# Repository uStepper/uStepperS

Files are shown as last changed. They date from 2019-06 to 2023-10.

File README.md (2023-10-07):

# uStepper S

The library contains support for driving the stepper, reading out encoder data. A few examples are included to show the functionality of the library.
The library is supported and tested with in Arduino IDE 1.8.11.

For more information, visit www.ustepper.com

## !! EEPROM Usage information !!

Please be aware that the uStepper uses the EEPROM to store settings related to the Dropin application.
If you are not using this, then this has no impact for your application, and you can ignore this section !

EEPROM address 0 to 15 contains the different settings for dropin. If your application uses the EEPROM,
Please use another location than these !

## Installation

Installation is split into two parts - Hardware and Library. Both are required to use the uStepper S boards.

### Hardware Installation 

### Instructions for users with the hardware for the original uStepper (the one before S and S lite) installed

To add hardware support for uStepper in the Arduino IDE (1.8.8+) do the following:
 - Open Arduino
 - Go to "Tools->Board->Boards Manager..."
 - Search for "uStepper"
 - Choose the "uStepper" board and press "Remove" button
 - close the Boards Manager
 - Go to "File->preferences"
 - Almost at the bottom there is a field stating: "Additional Boards Manager URLs" replace your currently inserted uStepper URL this URL: https://raw.githubusercontent.com/uStepper/uStepperHardware/master/package_ustepper_index.json
 - Press OK
 - Go to "Tools->Board->Boards Manager..."
 - Go to the bottom (after it has loaded new files) select "uStepper by ON Development IVS" and press install

### Instructions for users new to uStepper

To add hardware support for uStepper in the Arduino IDE (1.8.8+) do the following:
 - Open Arduino
 - Go to "File->preferences"
 - Almost at the bottom there is a field stating: "Additional Boards Manager URLs" insert this url: https://raw.githubusercontent.com/uStepper/uStepperHardware/master/package_ustepper_index.json
 - Press OK
 - Go to "Tools->Board->Boards Manager..."
 - Go to the bottom (after it has loaded new files) select "uStepper by ON Development IVS" and press install

You have now added uStepper hardware support and should be able to select uStepper under tools -> boards.

### Library Installation

To add the uStepper S library do the following:
- Open Arduino IDE (Version 1.8.8 or above)
- Go to "Sketch->Include Library->Manage Libraries..."
- Search for "uStepper S"
- Select "uStepper S" and press install
- Close Library Manager

## Documentation
The documentation for this library can be found at the following URL:

http://ustepper.com/docs/usteppers/html/index.html

### MAC (and a few Windows) Users:
In order to make the uStepper S show up in the "ports" list, you need to install the VCP driver from the following link: 
https://www.silabs.com/products/development-tools/software/usb-to-uart-bridge-vcp-drivers

## Known bugs
- does not properly release motor in dropin mode

## Change Log
2.3.2:
- added new python control example
- fixed encoder stall examples
- removed debug setup of pin on portB as output
  
2.3.1:
- added 6 new examples

2.3.0:
- Changed Servo library (uStepperServo.cpp) to use timer PWM instead of polling to control servo motors. 
- Changed the servo library example to use the new servo implementation.
- Changed the 'stop' method at the uStepperS.cpp to wait until the motor realy stops movement. Thanks to Daniel-Walther for pointing it out.

2.2.1:
- Added timeout to homing function

2.2.0:
- Added function to get current driver speed in RPM (getDriverRPM())
- Fixed "getVelocity()" method of "uStepperDriver" class to use correct twos complement conversion
- Updated keywords
- Added two new examples:
	- GYROBalance: Example on how to use MPU6050 IMU with uStepper S 
	- SWiFiGUI: Example sketch to control the uStepper S with browser based GUI over WiFi

2.1.0:
- Fixed checkOrientation to work with Closed loop and dropin modes
- Fixed stallguard feature
- Modified examples to library update  

2.0.0:
- Changed name of "brake()" function in uStepper Class to "setBrakeMode()"
- Implemented "setBrakeMode()" function in uStepper Class to choose between freewheel, braking with low side fets shorted and brake with specified hold current. default = brake with low side fets shorted
- "setHome" argument of ustepper class "setup" function is now used
- Implemented "checkOrientation()" function in uStepper Class, to check the orientation of the motor cable, and invert direction if needed.
- Added 3 moves in "checkOrientation()" function in uStepper Class, to check orientation instead of just 1
- Removed check for motor cable orientation from "setup()" function in uStepper Class. Users actively needs to call the "checkOrientation" function from uStepper Class, if they need this feature, AFTER calling the "setup()" function
- Disabled driver on MCU reset while setting up, to avoid the motor spinning on startup if power was removed during motor movement
- Moved the absolute position counter into the encoder getangle function
- Added a LP filter on the absolute position data in the encoder function (so, getAngleMoved is filtered)
- Stall detection removed from timer1
- Variable filter depending on mode set in setup routine
- Removed obsolete things in setup routine and timer1
- Made new velocity measurement for encoder values
- Made the control threshold for closed loop control variable and intrduced a function for editing it
- Changed timer1 interrupt frequency to 2KhZ for all other modes than DROPIN
- Added option to choose how long the "checkOrientation()" function in UstepperS class should move during check
- Renamed "PID" to "CLOSEDLOOP" to avoid confusing the closed loop position mode with a PID controller. PID keyword is stall accepted for backwards compatibility

1.0.1:
- Fixed bug in functions to set acceleration and deceleration
- moved a couple of functions in uStepperDriver.h from public to protected section of class
- added documentation

1.0.0:
- Bug fixes
- New Dropin PID code
- Added dropin CLI interface
- Fixed stall detection, and added user sensitivity parameter

0.1.1:
- Bug fixes

0.1.0:	
- Initial release

<br /><span xmlns:dct="http://purl.org/dc/terms/" property="dct:title">uStepper</span> by <a xmlns:cc="http://creativecommons.org/ns#" href="www.ustepper.com" property="cc:attributionName" rel="cc:attributionURL">ON Development</a> is licensed under a <a rel="license" href="http://creativecommons.org/licenses/by-nc-sa/4.0/">Creative Commons Attribution-NonCommercial-ShareAlike 4.0 International License</a>.

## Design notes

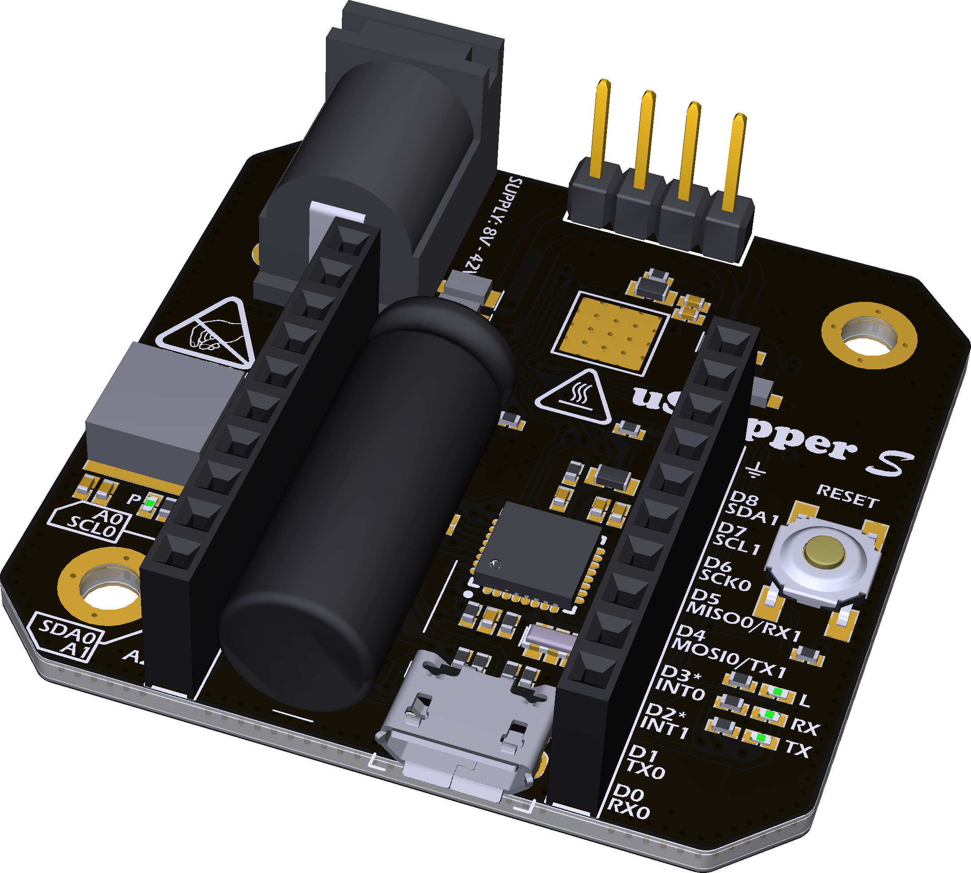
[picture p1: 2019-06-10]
Hardware/Board.png

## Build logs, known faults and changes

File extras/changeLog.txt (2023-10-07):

Changelog - uStepper S library
----------------------------
Version 2.3.2:
- added new python control example
- fixed encoder stall examples
- removed debug setup of pin on portB as output

Version 2.3.1:
	- added 6 new examples

Version 2.3.0:
	- Changed Servo library (uStepperServo.cpp) to use timer PWM instead of polling to control servo motors. 
	- Changed the servo library example to use the new servo implementation.
	- Changed the 'stop' method at the uStepperS.cpp to wait until the motor realy stops movement. Thanks to Daniel-Walther for pointing it out.

Version 2.2.1:
	- Added timeout to homing function

Version 2.2.0:
	- Added function to get current driver speed in RPM (getDriverRPM())
	- Fixed "getVelocity()" method of "uStepperDriver" class to use correct twos complement conversion
	- Updated keywords
	- Added two new examples:
		- GYROBalance: Example on how to use MPU6050 IMU with uStepper S 
		- SWiFiGUI: Example sketch to control the uStepper S with browser based GUI over WiFi

Version 2.1.0:
	- Fixed checkOrientation to work with Closed loop and dropin modes
	- Fixed stallguard feature
	- Modified examples to library update

Version 2.1.0:
	- Fixed checkOrientation to work with Closed loop and dropin modes
	- Fixed stallguard feature
	- Modified examples to library update  
	
Version 2.0.0:
	- Changed name of "brake()" function in uStepper Class to "setBrakeMode()"
	- Implemented "setBrakeMode()" function in uStepper Class to choose between freewheel, braking with low side fets shorted and brake with specified hold current. default = brake with low side fets shorted
	- "setHome" argument of ustepper class "setup" function is now used
	- Implemented "checkOrientation()" function in uStepper Class, to check the orientation of the motor cable, and invert direction if needed.
	- Added 3 moves in "checkOrientation()" function in uStepper Class, to check orientation instead of just 1
	- Removed check for motor cable orientation from "setup()" function in uStepper Class. Users actively needs to call the "checkOrientation" function from uStepper Class, if they need this feature, AFTER calling the "setup()" function
	- Disabled driver on MCU reset while setting up, to avoid the motor spinning on startup if power was removed during motor movement
	- Moved the absolute position counter into the encoder getangle function
	- Added a LP filter on the absolute position data in the encoder function (so, getAngleMoved is filtered)
	- Stall detection removed from timer1
	- Variable filter depending on mode set in setup routine
	- Removed obsolete things in setup routine and timer1
	- Made new velocity measurement for encoder values
	- Made the control threshold for closed loop control variable and intrduced a function for editing it
	- Changed timer1 interrupt frequency to 2KhZ for all other modes than DROPIN
	- Added option to choose how long the "checkOrientation()" function in UstepperS class should move during check
	- Renamed "PID" to "CLOSEDLOOP" to avoid confusing the closed loop position mode with a PID controller. PID keyword is stall accepted for backwards compatibility

Version 1.0.1:
	- Fixed bug in functions to set acceleration and deceleration
	- moved a couple of functions in uStepperDriver.h from public to protected section of class
	- added documentation
	
Version 1.0.0:
	- Bug fixes
	- New Dropin PID code
	- Added dropin CLI interface
	- Fixed stall detection, and added user sensitivity parameter

Version 0.1.1:
	- Bug fixes

Version 0.1.0:	
	- Initial release

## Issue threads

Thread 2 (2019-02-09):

Update readme

ghulands, 2019-02-09:
The readme says to follow the original documentation which talks about the ftdichip vcp. uStepper S uses the Silicon Labs VCP. It might save someone else 10 minutes why the port doesn't show up in the Arduino environment. ;-)

uStepper, 2019-02-10:
Thank you for noticing !
I will have the readme updated soon. are you using a mac?
Best Regards,
Thomas Olsen

ghulands, 2019-02-18:
Yes, using macOS.

sfandersen, 2019-02-19:
I am using Windows 10. It the uStepperS did not show up as a serial port before I downloaded this driver: https://www.silabs.com/products/development-tools/software/usb-to-uart-bridge-vcp-drivers

uStepper, 2019-02-27:
Thanks for pointing out that this issue can also occur on windows 10 !

Closed 2019-02-27.

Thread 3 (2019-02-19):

The max velocity seems wrong

sfandersen, 2019-02-19:
I think the max value that can be set is for VMAX should be 0x7FFE00

See the driver documentation:
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

I think the code should be:
	if( abs(velocity * this->microSteps) > (float)(0x7FFE00)) {
		velocity = (float)0x7FFE00 / this->microSteps;
	}

See:
https://github.com/uStepper/uStepperS/blob/2ae15273d868393d964261376dd657c965204c8a/src/uStepperS.cpp#L291

uStepper, 2019-02-27:
You are correct, this will be updated in next release !

sfandersen, 2019-04-29:
I would suggest only closing the bugs that are fixed.

Closed 2019-02-27.

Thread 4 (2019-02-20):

Overflow bug in stepper setup

matt-phair, 2019-02-20:
in `uStepperS::setup`, there is the line:

```
this->angleToStep = (float)(this->fullSteps*this->microSteps)/360.0;
```

by default, `microSteps` is `256` so if we call `setup` with `stepsPerRevolution` equal to anything over 256, the above will overflow.

This is a problem for (as an example) this motor: https://www.omc-stepperonline.com/nema-17-bipolar-09deg-46ncm-651ozin-2a-28v-42x42x48mm-4-wires-17hm19-2004s.html which has 400 steps per revolution.

The code could be corrected to be something like:

```
this->angleToStep = (float)this->fullSteps * (float)this->microSteps / 360.0
```

uStepper, 2019-04-09:
corrected for the upcoming version . Thanks for the input !

Closed 2019-04-09.

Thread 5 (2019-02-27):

No hard stop

matt-phair, 2019-02-27:
I'm working on implementing my own limit switches, andI might be missing something, but I can't reliably achieve a full hard stop.

`uStepper::stop()` still does a ramp down. At the moment, I'm trying to use something like this:

```
void stop() {
  stepper.driver.reset();
  delay(1000);
  stepper.setup(NORMAL, STEPS_PER_REVOLUTION);
  stepper.setMaxAcceleration(MAX_ACCELERATION);
  stepper.setMaxVelocity(MAX_VELOCITY);
  delay(1000);
}
```

But if this happens in the middle of a very long move, when `stepper.setup(...)` is called, it tries to finish the move it was originally in. If I can reset the current ramp profile, then maybe that will help the reset process?

Or if I'm way off base and there's a simple single line function to call to stop, then can someone point me in that direction?

uStepper, 2019-02-27:
Hi Matt,

A simple solution is to just set the max acceleration to a high value, call the stop function, and set the acceleration value back to normal after the motor has stopped:

`
void stop() {
  stepper.setMaxAcceleration(65535);
  stepper.stop();
  delay(100);
  stepper.setMaxAcceleration(MAX_ACCELERATION);
}
`
I hope this can help solving your issue

matt-phair, 2019-02-27:
@uStepper that solved it, thanks!

Closed 2019-02-27.

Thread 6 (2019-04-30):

Arduino error: Error compiling for board uStepper

derekcovill, 2019-04-30:
Hi there , I recently purchased a ustepper S, and I’ve installed the libraries for this in my Arduino (v 1.8.9...I'm not using the app) and have selected the uStepper board at the bottom of the list of boards, but when I try to run one of the example sketches (e.g. bounce) there is always the following error……….

In file included from
 ...\Arduino\libraries\uStepper_S\Examples\Bounce\Bounce.ino:1:0:

...\Arduino\libraries\uStepper_S\src/uStepperS.h:38:3: error: #error !!This library only supports the ATmega328PB MCU!!

  #error !!This library only supports the ATmega328PB MCU!!

   ^

exit status 1
Error compiling for board uStepper.

Just wondering if you have any advice for this? I’ve tried all the examples from uStepper, UstepperS and UstepperS lite also…

uStepper, 2019-04-30:
Hi Derek,

The problem is that you selected the "ustepper" board. You need to select the "ustepper S" board , if this is the type you have

Best regards
Thomas olsen

derekcovill, 2019-04-30:
Hi Thomas, but there doesn’t seem to be a ustepper S option? [image1.jpeg]

On 30 Apr 2019, at 17:26, uStepper <notifications@github.com<mailto:notifications@github.com>> wrote:

Hi Derek,

The problem is that you selected the "ustepper" board. You need to select the "ustepper S" board , if this is the type you have

Best regards
Thomas olsen

—
You are receiving this because you authored the thread.
Reply to this email directly, view it on GitHub<https://github.com/uStepper/uStepperS/issues/6#issuecomment-488020625>, or mute the thread<https://github.com/notifications/unsubscribe-auth/AKRZVYPERNVGE63YAOI343DPTBXMVANCNFSM4HJMD54A>.

___________________________________________________________
This email has been scanned by MessageLabs' Email Security System
on behalf of the University of Brighton. For more information see:
https://staff.brighton.ac.uk/is/computing/Pages/Email/spam.aspx

___________________________________________________________
This email has been scanned by MessageLabs' Email Security System
on behalf of the University of Brighton. For more information see:
https://staff.brighton.ac.uk/is/computing/Pages/Email/spam.aspx

derekcovill, 2019-04-30:
I did that but will try it again, perhaps I didn’t do it correctly, fingers crossed and many thanks for your help!

On 30 Apr 2019, at 17:55, uStepper <notifications@github.com<mailto:notifications@github.com>> wrote:

Then it is because you only installed the library, and not the hardware package. Please read the "hardware" part under "installation" on the readme page:
https://github.com/uStepper/uStepperS/blob/master/README.md

—
You are receiving this because you authored the thread.
Reply to this email directly, view it on GitHub<https://github.com/uStepper/uStepperS/issues/6#issuecomment-488030467>, or mute the thread<https://github.com/notifications/unsubscribe-auth/AKRZVYIVKJEQKI5FCA6GBI3PTB2W5ANCNFSM4HJMD54A>.

___________________________________________________________
This email has been scanned by MessageLabs' Email Security System
on behalf of the University of Brighton. For more information see:
https://staff.brighton.ac.uk/is/computing/Pages/Email/spam.aspx

___________________________________________________________
This email has been scanned by MessageLabs' Email Security System
on behalf of the University of Brighton. For more information see:
https://staff.brighton.ac.uk/is/computing/Pages/Email/spam.aspx

derekcovill, 2019-04-30:
Ok, I uninstalled the old one, updated it to the new one and that seemed to work, many thanks!

From: uStepper <notifications@github.com>
Reply-To: uStepper/uStepperS <reply@reply.github.com>
Date: Tuesday, 30 April 2019 at 17:55
To: uStepper/uStepperS <uStepperS@noreply.github.com>
Cc: Derek Covill <D.Covill@brighton.ac.uk>, Author <author@noreply.github.com>
Subject: Re: [uStepper/uStepperS] Arduino error: Error compiling for board uStepper (#6)

Then it is because you only installed the library, and not the hardware package. Please read the "hardware" part under "installation" on the readme page:
https://github.com/uStepper/uStepperS/blob/master/README.md

—
You are receiving this because you authored the thread.
Reply to this email directly, view it on GitHub<https://github.com/uStepper/uStepperS/issues/6#issuecomment-488030467>, or mute the thread<https://github.com/notifications/unsubscribe-auth/AKRZVYIVKJEQKI5FCA6GBI3PTB2W5ANCNFSM4HJMD54A>.

___________________________________________________________
This email has been scanned by MessageLabs' Email Security System
on behalf of the University of Brighton. For more information see:
https://staff.brighton.ac.uk/is/computing/Pages/Email/spam.aspx

___________________________________________________________
This email has been scanned by MessageLabs' Email Security System
on behalf of the University of Brighton. For more information see:
https://staff.brighton.ac.uk/is/computing/Pages/Email/spam.aspx

Closed 2019-05-15.

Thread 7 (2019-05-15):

Changing Hold Current bug

justinchan91, 2019-05-15:
When changing the max current to 80% using:

void setup(void)
{
 stepper.setup(PID);
  delay(1000);
  stepper.setMaxAcceleration(500);
  stepper.setMaxVelocity(800);
  **stepper.setCurrent(80.0);**
}

void loop(void){
  if(!stepper.getMotorState())
  {
    delay(500);
    stepper.moveToAngle(angle);
    angle = -angle;
  }

Any value around 70%-100% gives a random jerking. At start, while moving and sometimes at end where the motor stalls and then continues hap-hazardly.

max value according to datasheet is 31. The driver scales the input float and converts to a range of ints 0-31.

Using a stepper motor rated for up to 3A. Also tried w a smaller stepper motor-same issue.

uStepper, 2019-05-15:
Hi Justin,

Thank you for pointing this issue out. I will look into the cause and come up with a solution.

Best Regards,
Thomas Olsen

greyltc, 2020-02-02:
I see this too.

This isn't just for holding current though, it's for running current. My motors become increasingly unstable and unusable with current values beyond 50%. @uStepper, have you made any progress with solving this bug since last May?

Being limited to 50% of the design & advertised current or less seems like a pretty big deal.

uStepper, 2020-02-04:
Hi,

We have run a long term test on the NEMA 17 motors we sell and use and we can't get the behavior you describe.

And yes it is reasonable to being limited to 50% max current without adding cooling. There's a lot of heat dissipated from the TMC5130 and thus things will heat up unless you add active cooling. It is the same as for any other stepper driver like the popular StepStick style drivers.

What motors are you using? And what supply voltage?

sriram198198, 2020-02-15:
Hi team,

As you have mentioned that you have tested and was unable to reproduce the behavior. I would like to know what is the max current you have tested with ?

I am planning to buy few tens of pieces but for my application 50 Percent ( 1 Amp of current is not sufficient in some cases)

I am curious to know If I Could go a bit higher like 60-70 Percent Current so that I get 1.5 Amps to 1.68 Amps out of Ustepper S version.

Thank you,
Sriram.

uStepper, 2020-02-17:
Hi,

So we did an additional test on a motor with a rated current of 2.1A. The test was done using the run continous example. A 24 V lab supply capable of providing 3A was used and for the tests with FAN I used a 24V fan mounted in a fancover. Heatsinks were mounted on all tests.
It is not surprising that the driver gets hot since the on resistance of the TMC5130 can be as high as ~1ohm per half bridge meaning that at full current 4W is developed in heat - which is quite a bit.

Motor: 17HS24-2104S
Room temperature: 22 deg C

Test 1:
Current setting Run/Hold: 50/50 %
Surface chip temp after 30 min: 75.3degree

Test 2:
The same as Test 1 but with fan:
Surface chip temp after 30 min: 42.6deg C

Test 3:
~30min - stopped due to fear of burning the motor
Current setting Run/Hold: 100/100 %
Surface chip temp after ~30 min: 91.3deg C
Motor temperature: 57deg C

None of the test showed any issues with movement

We do not recommend running your driver at high tempepratures. We do recommend that some thought is given on how you use the driver, e.g. lower hold current, do not use brake if not necessary (to avoid heating during standstill) and limit running current to what is necessary. Furthermore, keep the supply voltage as low as you can since a higher supply will generate more heat on the board in general - both on switch mode regulator and driver. So, if it is not strictly needed to run at e.g. 36V then lower your supply voltage to what is actually required. A good starting point is 12V which is sufficient for most applications.

wffbos, 2020-02-26:
Hi,
I can't find in the documentation how to translate the current which is set in percent to actual current (amperes). I can find this:
http://ustepper.com/docs/usteppers/html/uStepperS_8cpp_source.html#l00392
`void uStepperS::setCurrent( double current )
 {
     if( current <= 100.0 && current >= 0.0){
         // The current needs to be in the range of 0-31
         this->driver.current = ceil(0.31 * current);
     }else{
         // If value is out of range, set default
         this->driver.current = 16;
     }

     driver.updateCurrent();
 }`
What unit is the value 0-31? Amperes? mili-amperes?
I guess the driver can't be that smart and know the max current for my motor?

uStepper, 2020-02-26:
Hi,

the documentation is here:
[http://ustepper.com/docs/usteppers/html/classuStepperS.html#ac74e343f7ad81aa5c54a68f2514807fe](url)

the input to the function is in percent (0-100), and the driver is a 2A driver, so 0% = 0A and 100% = 2A.
the 0-31 values you refer to are the input for the register in the driver

no, the driver does not know your motor rating, so you will need to adjust this accordingly

Best Regards,
Thomas Olsen

Closed 2020-07-11.

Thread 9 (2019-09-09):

Reading encoder data

GabrielGms, 2019-09-09:
Hello, i'm working on my research and this board is exactly what i need, but i have a specific need, read the data used in PID controller on another board. I don't need write data, only read to control a second code, running in another microcontroller, using the output error, this is possible? how?

uStepper, 2019-09-09:
Hi,
That would require alteration of the library. It can be done, but it require some coding from you.

Best regards, Mogens

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

uStepper, 2019-10-16:
Closing issue due to long inactivity

Closed 2019-10-16.

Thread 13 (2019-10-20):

Available/reserverd features?

esaheiskanen, 2019-10-20:
Hi!

Which 328pb featuers are reserved for ustepper s? I just noteced that serial1 (pins 5&6) interfere with stepperdriver. Is there a way top make serial1 to work?

uStepper, 2019-10-21:
Hi Esa,

The Serial1 feature is not reserved on either the uStepper S or S Lite, and does not interfere with the stepper driver. I am using the Serial1 in some of my sketches to get data from a wifi module (without any hardware/software modification)

On the uStepper S, SPI1 is used for the stepper driver, so this peripheral is not available to the user. The schematics are available under the hardware folder in this repository, if you want to take a closer look on which peripherals and pins are available on the pin headers

Best Regards,
Thomas Olsen

Closed 2020-02-04.

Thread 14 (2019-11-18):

uStepperS::setup()'s "setHome" parameter appears to do nothing

JRVeale, 2019-11-18:
Looking in uStepperS.cpp, I can see `encoder.setHome()` is called twice during `setup()` (on first glance it seems to be being used to determine which direction to set the driver's direction to), regardless of the value of the `bool` parameter `setHome`. It appears that the `setHome` is actually not used anywhere at all.

One may want to use the encoder to receive absolute angles, and therefore wish to prevent encoder's `setHome()` function from being called by setting the value of `setHome` in `setup()` accordingly.

If I've understood the library correctly from my brief look, I suggest changing `setup()` to call `encoder.getAngle()` twice to determine the direction to set for the driver (instead of calling `encoder.setHome()` at the start of `setup()` and then using `encoder.getAngleMoved()`). The final call to `encoder.setHome()` will then only occur if `setup()` has been called with the `setHome` parameter as `true`. This should preserve current behaviour while adding the option to leave the encoder as absolute.

(As an aside, thanks for open-sourcing and I have to say I appreciate how easy it is to skim through the uStepper code and understand the structure of what appears to be going on.)

JRVeale, 2019-11-18:
Actually, I'll try this quickly and if it seems to work without obvious issue I'll open a PR

uStepper, 2019-11-19:
Hi James,

Your suggestion is exactly how it is supposed to work. I don't know how we overlooked this, but the feature is not implemented for some reason. I will add this to the next release !

It is good to hear you are happy with the open-sourcing and the code structure, although i personally think it has gotten pretty messy in most places and could use a clean up ! ;)

Best Regards,
Thomas Olsen

JRVeale, 2019-11-19:
Far be it from me to judge anyone else's code smell!

uStepper, 2020-07-11:
Fixed :)

Best regards,
Mogens

Closed 2020-07-11.

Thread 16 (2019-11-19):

Question: Purpose of 10s delay during setup in DROPIN mode?

JRVeale, 2019-11-19:
Question in the title. Are there any adverse effects by removing (or shortening) this delay?

uStepper, 2019-11-30:
Hi,

The reason this delay was added initially was because during power up, when the printer controller board was connected to the uSteppers, some "garbage" signals sometimes occured on the step/dir/ena lines, making the system behave strange.

That said, this delay might not be needed in all setups, we just chose to keep it, as it was needed in our case

Best Regards,
Thomas Olsen

Closed 2020-02-04.

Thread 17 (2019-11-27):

SetHome - is my requirement possible

thehelpless, 2019-11-27:
Hi,

I am new to the ustepper and ustepper library.

I am building a camera slider on a linear belt driven rail using a nema 23 and a ustepperS

I want to create a homing routing that does the following (can be on each reset - no need to store long term)

On power on;

move the gantry CW and detect "home" position and set this as "0" steps
move the gantry CCW and detect "end" position and set this as "nSteps" from home.

I want this to be in steps rather than degrees (although I could divide degrees by step angle if needed)

Is the above possible with the ustepper library?

Thanks

uStepper, 2019-11-30:
Hi,
Yes, the above is possible by using the "moveToEnd()" function of the library. This function will move in your desired direction until it hits the endpoint, and return the distance from your starting point to the endpoint (in degrees):

`float railLength;`
`stepper.moveToEnd(CW,0.9);`
`stepper.encoder.setHome();`
`railLength = stepper.moveToEnd(CCW,0.9);`

the "0.9" parameter is used to set the stall detection sensitivity, and should be between 0 and 1, with lower numbers being more sensitive to stall detections.

I hope the above was helpful !

Best Regards,
Thomas Olsen

thehelpless, 2019-12-05:
Hi Thomas,

Thanks for your input / help and the time taken to read my mail! - the code example you provided worked perfectly,

`#include <uStepperS.h>

uStepperS stepper;
float railLength;
int railSteps;

void setup() {
  stepper.setup();
  Serial.begin(9600);

   while(!Serial.available());
  stepper.moveToEnd(CCW,0.9);
  stepper.encoder.setHome();
  railLength = stepper.moveToEnd(CW,0.9);
  Serial.println(railLength);
  railSteps = railLength/1.8;

}`

Thanks again

Closed 2019-12-05.

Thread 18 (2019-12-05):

moveAngle v moveToAngle

thehelpless, 2019-12-05:
Hi,

In the class list for the uStepper S there is both moveAngle and moveToAngle.
The descriptions for the two are identical, however the code is not.

Am i right that moveAngle is relative while moveToAngle is absolute based on the initiation of PID and using setHome?

Thanks

uStepper, 2019-12-08:
Hi,

That is not intended that the documentation is identical.

But yes, you are absolutely correct

Best Regards,
Thomas Olsen

uStepper, 2020-07-11:
Corrected the description in the develop branch

Best regards,
Mogens

Closed 2020-07-11.

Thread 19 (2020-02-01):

StallGuard2 support?

greyltc, 2020-02-01:
It seems like your stall detection implementation here could be improved. Why not make use of the StallGuard2 feature in the TMC5130A? That should be much more robust and performant than what you have now.

uStepper, 2020-02-04:
Hi,

We did it the way we did to make the implementation the same for both the S and the S-lite. But we are looking in to stallguard already as we could use the processing power for other tasks than stall detection.

greyltc, 2020-02-04:
Also, the driver IC can keep track of the encoder counts so you don't have to do that on the microcontroller.

uStepper, 2020-02-05:
Hi,

I agree with you, that could be helpful, however there are a few issues, why this may not be an ideal solution

first of all we would loose 2 bits of resolution by using the ABI interface of the encoder.

secondly, one of our current issues is noise on the encoder readings, which we are currently working on solving by adding a filter to the encoder output. this noise will be present on the ABI output aswell, and since it goes directly into the driver chip, we won't be able to mitigate the problem at all

Closed 2021-01-22.

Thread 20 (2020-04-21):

Help walk me through setting up Ustepper S with 3D printer

dshield55, 2020-04-21:
Hoping for a walkthrough for using uStepper S boards on the X and Y of a 3D printer.

I'm a beginner. From info on the website, I think right now I have a PID problem. But I don't know how to determine or why to change either of those 3 variables.

I first tried the stock dropin example sketch that had P-75, I-7, D-1 (why is it higher than suggested PIDs elsewhere?)

I changed it to P-0.5, I-0.5, D-0 like the uStepper S product sheet said to try. That doesn't work either.

I don't know where to go from here because I have no idea how to determine what to change them to or why I'm changing them.

I think I set the hardware up correctly according to instructions and I have the latest board and library installed in Arduino IDE 1.8.1.2. I have an SKR V1.4 Turbo printer board with Marlin 2.0.5.2 firmware that was setup and working well. I commented out the drivers for the X and Y axis so it uses default settings for drivers and I can just run enable, step, dir, and ground pins from the driver sockets in the board up to the uStepperS.

I've attempted to print a calibration square. Shifts happen every time the direction is changed.  Normal behavior for my printer without uStepper is maybe once in 100 layers a single noticeable shift happens. This behaviour would be like a continuous shift that never stops shifting and each new layer starts farther up and to the right of the layer before it.

If I take motor off of printer and just run the motor with uStepperS, any time I change direction, it'll end up as much as 90 degrees off. Once I've gone one direction long enough it will consistently always advance the way it should, but if I switch directions again, it's going to get thrown off. There's lots of sudden accelerations, screeching, and knocking in the motor.

dshield55, 2020-04-28:
Problem was with magnets slipping during operation, not with PID.

Closed 2020-04-28.

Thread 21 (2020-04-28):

Permission denied in objcopy crtatmega328pb.o

HermanEldering, 2020-04-28:
I am using the Windows Store version of Arduino. When using the uStepperS board I get a permission denied error when it attempts to copy the crtatmega328pb file.

From this forum post it also appears to happen when the Arduino IDE is installed inside the program files folder: https://forum.arduino.cc/index.php?topic=638028.0

For now I've seemed to fix it by commenting out the lines below in the file "packages\uStepper\hardware\avr\2.2.0\platform.txt". I'm not sure if this will cause problems somewhere else but with these changes the bounce example compiles and runs on the board.

```
# Copy the startup and c runtime libs to the right folder / thx to elector
#recipe.hooks.linking.prelink.1.pattern="{compiler.path}{compiler.objcopy.cmd}" "{runtime.platform.path}/tools/lib/crtatmega328pb.o" "{runtime.tools.avr-gcc.path}/avr/lib/avr5/crtatmega328pb.o"
#recipe.hooks.linking.prelink.2.pattern="{compiler.path}{compiler.objcopy.cmd}" "{runtime.platform.path}/tools/lib/crtatmega328pb.o" "{runtime.tools.avr-gcc.path}/avr/lib/avr5/crtm328pb.o"
#recipe.hooks.linking.prelink.3.pattern="{compiler.path}{compiler.objcopy.cmd}" "{runtime.platform.path}/tools/lib/libatmega328pb.a" "{runtime.tools.avr-gcc.path}/avr/lib/avr5/libatmega328pb.a"
```

uStepper, 2020-04-30:
Hi Herman,

That issue is related to the windows store version of Arduino IDE, which currently have issue with some functions and boards. we recommend that you use the version downloaded directly from arduino.cc.

Best Regards,
Thomas Olsen

Closed 2020-04-30.

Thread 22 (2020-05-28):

Difference between MovedAngle and motor steps

Nestilaos, 2020-05-28:
Hi,

I observed with release 2.0.0 a difference between the moved angle and the steps ran by the motor. I am quite sure that the motor did not loose steps.

When running 51200 steps into one direction and then going back the initial angle is missed by approx. 20-40 deg according to getAngleMoved().

Is this anything known?

Regards.

Nestilaos, 2020-05-29:
I found the issue. The distance between encoder and magnet was too high. The status bit for "weak magnet field" was set.

Neither the "old" mounting bracket from uStepper/uStepper S-lite nor the newer one that allows permanent mounting can be used without modifications. The distance between magnet and encoder is just too high.

I could put some stripes of Tesa below the magnet. Now everything is working correctly as far as I can tell.

uStepper, 2020-07-11:
Hi,

Yeah we have noticed that the magnet strength is on the weak side. We cant recall this with our stock motors here though...

sliangder, 2021-05-09:
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

Closed 2020-07-11.

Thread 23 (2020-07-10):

ShaftOrientiation is not correctly maintained

Nestilaos, 2020-07-10:
Shaft orientation is set in the GCONF register of the driver and correctly set in the corresponding function inside uStepperDriver.cpp.

Unfortunately, the bit is not respected and set to zero, as soon as
- uStepperDriver::enableStealth()
- uStepperDriver::enableStallguard( int8_t threshold, bool stopOnStall )
- uStepperDriver::disableStallguard( void )
are called.

Therefore, in most of my scenarios the result of uStepperS::checkOrientation was not respected.

Best regards.

uStepper, 2020-07-11:
Hi - good catch :) We were already working on it and I have just pushed the corrected to the develop branch. When tested by a second party in our group we will merge into master and make a release with the fix.

Closed 2020-07-11.

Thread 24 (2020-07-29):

[FR] Support for Marlin 2.0.X Closed-loop controller function?

felixekman, 2020-07-29:
Are there any plans to expand support for Drop-in/replacement to be compatible with the new Marlin Firmware closed-loop controller functions? At a glance, it does not seem to be too difficult as it only requires the addition of two pins/variables:

#EXTERNAL_CLOSED_LOOP_CONTROLLER

CLOSED_LOOP_ENABLE_PIN        -1
CLOSED_LOOP_MOVE_COMPLETE_PIN -1

uStepper, 2023-08-13:
Support for the Marlin closed-loop firmware will not be implemented but it should be possible to do this by adding some functionality to our closedloop sketch for those two required I/O's

Closed 2023-08-13.

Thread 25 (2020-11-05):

example on how to use the other pins?

RobertoPuglieseFusco, 2020-11-05:
where can I find an example on how to use the other available pins?
for instance use PWM enabled pin to dim a light.
Thanks!

uStepper, 2021-01-22:
Hi Roberto,

This is done the same way as any other Arduino Board.
For general input/output pin usage check this guide:
https://www.allaboutcircuits.com/projects/learn-how-to-use-the-arduinos-digital-i-o/

for PWM, check out the following:
https://create.arduino.cc/projecthub/muhammad-aqib/arduino-pwm-tutorial-ae9d71

Best Regards,
Thomas Olsen

Closed 2021-01-22.

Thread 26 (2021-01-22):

Error compiling Continous.ino  / EEPROM / crtatmega328pb.o

LibrEars, 2021-01-22:
Hi uStepper-Team,

my trial to get the uStepperS working failed. I am running Debian 10 GNU/Linux and installed a new Arduino IDE via flatpack /flathub (v1.8.13) and followed the [steps](https://github.com/uStepper/uStepperS#instructions-for-users-new-to-ustepper) to install the uStepperS hard- and software.

Then I downloaded the Continous.ino example which does not compile (see error output below) - I even flashed the bootloader to be sure.

Do you now what might cause the error?  Also I am confused with the description of the EEPROM usage - an example-code or link for further information would help.

Thank you very much
LibrEars

```
Arduino: 1.8.13 (Linux), Board: "uStepperS"

/app/Arduino/arduino-builder -dump-prefs -logger=machine -hardware /app/Arduino/hardware -hardware /home/user/.arduino15/packages -tools /app/Arduino/tools-builder -tools /app/Arduino/hardware/tools/avr -tools /home/user/.arduino15/packages -built-in-libraries /app/Arduino/libraries -libraries /home/user/Arduino/libraries -fqbn=uStepper:avr:uStepperS -vid-pid=10C4_EA60 -ide-version=10813 -build-path /tmp/arduino_build_119629 -warnings=all -build-cache /tmp/arduino_cache_755599 -prefs=build.warn_data_percentage=75 -prefs=runtime.tools.avr-gcc.path=/app/Arduino/hardware/tools/avr -prefs=runtime.tools.avr-gcc-7.3.0-atmel3.6.1-arduino7.path=/app/Arduino/hardware/tools/avr -prefs=runtime.tools.avrdude.path=/app/Arduino/hardware/tools/avr -prefs=runtime.tools.avrdude-6.3.0-arduino17.path=/app/Arduino/hardware/tools/avr -prefs=runtime.tools.arduinoOTA.path=/app/Arduino/hardware/tools/avr -prefs=runtime.tools.arduinoOTA-1.3.0.path=/app/Arduino/hardware/tools/avr -verbose /home/user/Examples/Continous.ino/Continous/Continous.ino
/app/Arduino/arduino-builder -compile -logger=machine -hardware /app/Arduino/hardware -hardware /home/user/.arduino15/packages -tools /app/Arduino/tools-builder -tools /app/Arduino/hardware/tools/avr -tools /home/user/.arduino15/packages -built-in-libraries /app/Arduino/libraries -libraries /home/user/Arduino/libraries -fqbn=uStepper:avr:uStepperS -vid-pid=10C4_EA60 -ide-version=10813 -build-path /tmp/arduino_build_119629 -warnings=all -build-cache /tmp/arduino_cache_755599 -prefs=build.warn_data_percentage=75 -prefs=runtime.tools.avr-gcc.path=/app/Arduino/hardware/tools/avr -prefs=runtime.tools.avr-gcc-7.3.0-atmel3.6.1-arduino7.path=/app/Arduino/hardware/tools/avr -prefs=runtime.tools.avrdude.path=/app/Arduino/hardware/tools/avr -prefs=runtime.tools.avrdude-6.3.0-arduino17.path=/app/Arduino/hardware/tools/avr -prefs=runtime.tools.arduinoOTA.path=/app/Arduino/hardware/tools/avr -prefs=runtime.tools.arduinoOTA-1.3.0.path=/app/Arduino/hardware/tools/avr -verbose /home/user/Examples/Continous.ino/Continous/Continous.ino
Using board 'uStepperS' from platform in folder: /home/user/.arduino15/packages/uStepper/hardware/avr/2.2.1
Using core 'arduino' from platform in folder: /app/Arduino/hardware/arduino/avr
Detecting libraries used...
/app/Arduino/hardware/tools/avr/bin/avr-g++ -c -g -Os -w -std=gnu++11 -fpermissive -fno-exceptions -ffunction-sections -fdata-sections -fno-threadsafe-statics -flto -w -x c++ -E -CC -mmcu=atmega328pb -DF_CPU=16000000L -DARDUINO=10813 -DARDUINO_AVR_USTEPPER_S -DARDUINO_ARCH_AVR -I/home/user/.arduino15/packages/uStepper/hardware/avr/2.2.1/tools/include -D__AVR_DEV_LIB_NAME__=m328pb -I/app/Arduino/hardware/arduino/avr/cores/arduino -I/home/user/.arduino15/packages/uStepper/hardware/avr/2.2.1/variants/ustepperS /tmp/arduino_build_119629/sketch/Continous.ino.cpp -o /dev/null -DARDUINO_LIB_DISCOVERY_PHASE
Alternatives for uStepperS.h: [uStepper_S@2.2.0]
ResolveLibrary(uStepperS.h)
  -> candidates: [uStepper_S@2.2.0]
/app/Arduino/hardware/tools/avr/bin/avr-g++ -c -g -Os -w -std=gnu++11 -fpermissive -fno-exceptions -ffunction-sections -fdata-sections -fno-threadsafe-statics -flto -w -x c++ -E -CC -mmcu=atmega328pb -DF_CPU=16000000L -DARDUINO=10813 -DARDUINO_AVR_USTEPPER_S -DARDUINO_ARCH_AVR -I/home/user/.arduino15/packages/uStepper/hardware/avr/2.2.1/tools/include -D__AVR_DEV_LIB_NAME__=m328pb -I/app/Arduino/hardware/arduino/avr/cores/arduino -I/home/user/.arduino15/packages/uStepper/hardware/avr/2.2.1/variants/ustepperS -I/home/user/Arduino/libraries/uStepper_S/src /tmp/arduino_build_119629/sketch/Continous.ino.cpp -o /dev/null -DARDUINO_LIB_DISCOVERY_PHASE
Alternatives for EEPROM.h: [EEPROM@2.0 EEPROM@2.0]
ResolveLibrary(EEPROM.h)
  -> candidates: [EEPROM@2.0 EEPROM@2.0]
/app/Arduino/hardware/tools/avr/bin/avr-g++ -c -g -Os -w -std=gnu++11 -fpermissive -fno-exceptions -ffunction-sections -fdata-sections -fno-threadsafe-statics -flto -w -x c++ -E -CC -mmcu=atmega328pb -DF_CPU=16000000L -DARDUINO=10813 -DARDUINO_AVR_USTEPPER_S -DARDUINO_ARCH_AVR -I/home/user/.arduino15/packages/uStepper/hardware/avr/2.2.1/tools/include -D__AVR_DEV_LIB_NAME__=m328pb -I/app/Arduino/hardware/arduino/avr/cores/arduino -I/home/user/.arduino15/packages/uStepper/hardware/avr/2.2.1/variants/ustepperS -I/home/user/Arduino/libraries/uStepper_S/src -I/home/user/.arduino15/packages/uStepper/hardware/avr/2.2.1/libraries/EEPROM/src /tmp/arduino_build_119629/sketch/Continous.ino.cpp -o /dev/null -DARDUINO_LIB_DISCOVERY_PHASE
Using cached library dependencies for file: /home/user/Arduino/libraries/uStepper_S/src/uStepperDriver.cpp
Using cached library dependencies for file: /home/user/Arduino/libraries/uStepper_S/src/uStepperEncoder.cpp
Using cached library dependencies for file: /home/user/Arduino/libraries/uStepper_S/src/uStepperS.cpp
Using cached library dependencies for file: /home/user/Arduino/libraries/uStepper_S/src/uStepperServo.cpp
Generating function prototypes...
/app/Arduino/hardware/tools/avr/bin/avr-g++ -c -g -Os -w -std=gnu++11 -fpermissive -fno-exceptions -ffunction-sections -fdata-sections -fno-threadsafe-statics -flto -w -x c++ -E -CC -mmcu=atmega328pb -DF_CPU=16000000L -DARDUINO=10813 -DARDUINO_AVR_USTEPPER_S -DARDUINO_ARCH_AVR -I/home/user/.arduino15/packages/uStepper/hardware/avr/2.2.1/tools/include -D__AVR_DEV_LIB_NAME__=m328pb -I/app/Arduino/hardware/arduino/avr/cores/arduino -I/home/user/.arduino15/packages/uStepper/hardware/avr/2.2.1/variants/ustepperS -I/home/user/Arduino/libraries/uStepper_S/src -I/home/user/.arduino15/packages/uStepper/hardware/avr/2.2.1/libraries/EEPROM/src /tmp/arduino_build_119629/sketch/Continous.ino.cpp -o /tmp/arduino_build_119629/preproc/ctags_target_for_gcc_minus_e.cpp -DARDUINO_LIB_DISCOVERY_PHASE
/app/Arduino/tools-builder/ctags/5.8-arduino11/ctags -u --language-force=c++ -f - --c++-kinds=svpf --fields=KSTtzns --line-directives /tmp/arduino_build_119629/preproc/ctags_target_for_gcc_minus_e.cpp
Compiling sketch...
/app/Arduino/hardware/tools/avr/bin/avr-g++ -c -g -Os -Wall -Wextra -std=gnu++11 -fpermissive -fno-exceptions -ffunction-sections -fdata-sections -fno-threadsafe-statics -MMD -flto -mmcu=atmega328pb -DF_CPU=16000000L -DARDUINO=10813 -DARDUINO_AVR_USTEPPER_S -DARDUINO_ARCH_AVR -I/home/user/.arduino15/packages/uStepper/hardware/avr/2.2.1/tools/include -D__AVR_DEV_LIB_NAME__=m328pb -I/app/Arduino/hardware/arduino/avr/cores/arduino -I/home/user/.arduino15/packages/uStepper/hardware/avr/2.2.1/variants/ustepperS -I/home/user/Arduino/libraries/uStepper_S/src -I/home/user/.arduino15/packages/uStepper/hardware/avr/2.2.1/libraries/EEPROM/src /tmp/arduino_build_119629/sketch/Continous.ino.cpp -o /tmp/arduino_build_119629/sketch/Continous.ino.cpp.o
cc1plus: warning: type qualifiers ignored on function return type [-Wignored-qualifiers]
cc1plus: warning: type qualifiers ignored on function return type [-Wignored-qualifiers]
In file included from /home/user/Arduino/libraries/uStepper_S/src/uStepperS.h:152:0,
                 from /home/user/Examples/Continous.ino/Continous/Continous.ino:9:
/home/user/.arduino15/packages/uStepper/hardware/avr/2.2.1/libraries/EEPROM/src/EEPROM.h:145:20: warning: 'EEPROM' defined but not used [-Wunused-variable]
 static EEPROMClass EEPROM;
                    ^~~~~~
Compiling libraries...
Compiling library "uStepper_S"
Using previously compiled file: /tmp/arduino_build_119629/libraries/uStepper_S/uStepperDriver.cpp.o
Using previously compiled file: /tmp/arduino_build_119629/libraries/uStepper_S/uStepperEncoder.cpp.o
Using previously compiled file: /tmp/arduino_build_119629/libraries/uStepper_S/uStepperS.cpp.o
Using previously compiled file: /tmp/arduino_build_119629/libraries/uStepper_S/uStepperServo.cpp.o
Compiling library "EEPROM"
Compiling core...
Using precompiled core: /tmp/arduino_cache_755599/core/core_uStepper_avr_uStepperS_c05e25cd8a3f9a150fee831f71269750.a
Linking everything together...
/app/Arduino/hardware/tools/avr/bin/avr-objcopy /home/user/.arduino15/packages/uStepper/hardware/avr/2.2.1/tools/lib/crtatmega328pb.o /app/Arduino/hardware/tools/avr/avr/lib/avr5/crtatmega328pb.o
/app/Arduino/hardware/tools/avr/bin/avr-objcopy:/app/Arduino/hardware/tools/avr/avr/lib/avr5/crtatmega328pb.o: Das Dateisystem ist nur lesbar
Multiple libraries were found for "EEPROM.h"
 Used: /home/user/.arduino15/packages/uStepper/hardware/avr/2.2.1/libraries/EEPROM
 Not used: /app/Arduino/hardware/arduino/avr/libraries/EEPROM
Using library uStepper_S at version 2.2.0 in folder: /home/user/Arduino/libraries/uStepper_S
Using library EEPROM at version 2.0 in folder: /home/user/.arduino15/packages/uStepper/hardware/avr/2.2.1/libraries/EEPROM
exit status 1
Error compiling for board uStepperS.

```

uStepper, 2021-01-22:
Hi LibrEars,

The problem is not with the bootloader or the uStepper hardware/software.
The problem is that the following file is not readable on your arduino IDE installation:
   /app/Arduino/hardware/tools/avr/avr/lib/avr5/crtatmega328pb.o

I would suggest you to install the portable arduino IDE, downloaded directly from the arduino.cc website instead of the package manager you used.

Best Regards,
Thomas Olsen

LibrEars, 2021-05-18:
This solved the problem - Thank you!

Hint: You can use a virtual machine if you do want to sandbox the IDE

Closed 2021-05-18.

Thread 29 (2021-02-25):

[feature requests] hardware reset and interrupt lines

greyltc, 2021-02-25:
I wonder if in the next hardware revision you make you could tie pin 10 on the TMC driver (VCC_IO) to a pin on the microcontroller (or at least allow it to pull that line down momentarily).

This would allow the microcontroller to properly reset the driver IC. I'm not sure if there's an easy way in the current design to get all the driver's registers into a known state (is there?).

Also, would be great to have SWN_DIAG0 (pin 26) and SWP_DIAG1 (pin 27) from the stepper driver on interrupt enabled pins of the microcontroller!

uStepper, 2023-10-07:
Hi,

uStepper S will not receive further updates to hardware, and only limited updates to software.

however, we will take it into our considerations for our newest product, uStepper S32.

Best Regards
uStepper Team

Closed 2023-10-07.

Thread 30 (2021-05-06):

VCP driver for Windows 10

ghulands, 2021-05-06:
Hi,
I'm trying to help my friend set up the uStepper S environment on Windows 10, but when I plug in the usb on it, Windows 10 is not creating a virtual com port.

Which Virtual COM port driver do i need to install for the devices to appear in the Aurdino IDE?

Thanks,
Greg

uStepper, 2021-05-11:
Hi Greg,

You should install the following VCP driver:
https://www.silabs.com/documents/public/software/CP210x_Windows_Drivers.zip

Best regards,
Thomas Olsen

Closed 2023-08-13.

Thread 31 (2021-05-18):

Can't get interrupts to work

LibrEars, 2021-05-18:
Hi all,

i am trying to attach a [mechanical kill-switch](https://de.rs-online.com/web/p/mikroschalter/6821529/) (pulldown) to my setup in order to stop the motor in case my 'platform crashes into an object'.

The code works with an arduino but sadly not with the uStepperS. The digital pin itself works so I guess there is a problem with the interrupts..

Can somebody help :)?

Here is the code:

```
// Code used to test a kill-switch (pulldown configuration - with an external 10k resistor and the +5V source) with uStepperS

//include libraries
#include <math.h>

//Stop-switches definitions
#define stopSwPin 3 // pin with interrupt

//global variables
volatile int stopMove=0;        //stop-switch output
void stop_isr();
void waitForSerial();

//runs once
void setup() {
  Serial.begin(115200); //115200 is baud rate of serial comm

  //setup stop switches
  pinMode(stopSwPin, INPUT);
  attachInterrupt(digitalPinToInterrupt(stopSwPin),stop_isr,RISING);
  stopMove=0;
}

//runs forever
void loop() {

  int i,input_char;

  Serial.println("\nStart test switches? [y/n]");
  waitForSerial();

  for(i=0; i<5; i++){

    //check if stop switch was pressed
    if(stopMove==HIGH){
      Serial.println("MOTOR STOPPED");
      break;
    }

    }

    Serial.println("\nContinue to next test? [y/n]");
    waitForSerial();

}

//functions

void waitForSerial(){
  char input_char;

  while(Serial.available()==0);
  do{
    input_char= (char)Serial.read();
  }
  while(input_char!='y');
}

//stop switch interrupt handler
void stop_isr(){ //keep this function small!

  stopMove=HIGH;

}
```

LibrEars, 2021-05-21:
hi again,

i checked with another code for a simple button and LED toggle ([from here](https://www.electronicshub.org/arduino-interrupts-tutorial/)).  Still it works on the arduino (here I used pin 13 for the LED) but not for the uStepperS :/

```
int ledPin = A2;
int buttonPin = 3; // use simple button (rotary)

int ledToggle;
int previousState = HIGH;
unsigned int previousPress;
volatile int buttonFlag;
int buttonDebounce = 20;

void setup()
{
  //interrupts();
  pinMode(ledPin, OUTPUT);
  pinMode(buttonPin, INPUT_PULLUP);
  attachInterrupt(digitalPinToInterrupt(3), button_ISR, CHANGE);
}

void loop()
{
  if((millis() - previousPress) > buttonDebounce && buttonFlag)
  {
    previousPress = millis();
    if(digitalRead(buttonPin) == LOW && previousState == HIGH)
    {
      ledToggle =! ledToggle;
      digitalWrite(ledPin, ledToggle);
      previousState = LOW;
    }

    else if(digitalRead(buttonPin) == HIGH && previousState == LOW)
    {
      previousState = HIGH;
    }
    buttonFlag = 0;
  }
}

void button_ISR()
{
  buttonFlag = 1;
}
```

LibrEars, 2021-06-11:
Hi Again,

i got some progress by using [Pin Change Interrupts](https://www.teachmemicro.com/arduino-interrupt-tutorial/). They are different than normal Interrupts ("might be a tiny bit slower and not that reliable because of that detection overhead (talking about micro seconds)") but there is an [arduino library](https://www.arduino.cc/reference/en/libraries/pinchangeinterrupt/).

Still it is very confusing and frustrating that normal interrupts do not work. Could it be, that they are already in use by the [dropin feature](https://ustepper.com/docs/usteppers/html/classuStepperS.html#a7d9af270acb55589631319b0f5460276)? In my understanding they should not as long as you do not use this feature actively in your code... ?

Here is an example code for Pin Change Interrupts:

```
#include "PinChangeInterrupt.h"

// Choose a valid PinChangeInterrupt pin of your Arduino board
#define buttonPin 3
int LEDPin = A2;

void setup()
{

  // set pin to input with a pullup, led to output
  pinMode(buttonPin, INPUT_PULLUP);
  pinMode(LEDPin, OUTPUT);

  // Manually blink once to test if LED is functional
  blinkLed();
  delay(1000);
  blinkLed();

  // Attach the new PinChangeInterrupt and enable event function below

}

void loop()
{
 // Nothing to do here
}

// ISR
void blinkLed(void) {
  // Switch Led state
  digitalWrite(LEDPin, !digitalRead(LEDPin));
}
```

uStepper, 2023-10-07:
Hi,

The problem is in the "digitalPinToInterrupt(3)" function, having an implementation error.

this is fixed in the development branch of the hardware package, which will be released soon

Best Regards,
uStepper Team

Closed 2023-10-07.

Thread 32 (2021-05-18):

i2C example - Grove-LCD display (RGB Backlight)?

LibrEars, 2021-05-18:
Hi all,

did someone get the I2C ports SDA1 and SCL1 (Digital pins D7 & D8) of the uStepperS up running? I tried to connect a grove-LCD display (RGB Backlight) but it did not work so far.

The examples of the [grove library](https://github.com/Seeed-Studio/Grove_LCD_RGB_Backlight) did not work and I also tried without success to detect the I2C ports in general with the i2c_scanner from the arduino uno examples (with and without the pins connected, code see below)

The scanner uses the wire library. Does someone knows if this should work in principle or is there more hard stuff necessary to get it running?

```
// --------------------------------------
// i2c_scanner
//
// Version 1
//    This program (or code that looks like it)
//    can be found in many places.
//    For example on the Arduino.cc forum.
//    The original author is not know.
// Version 2, Juni 2012, Using Arduino 1.0.1
//     Adapted to be as simple as possible by Arduino.cc user Krodal
// Version 3, Feb 26  2013
//    V3 by louarnold
// Version 4, March 3, 2013, Using Arduino 1.0.3
//    by Arduino.cc user Krodal.
//    Changes by louarnold removed.
//    Scanning addresses changed from 0...127 to 1...119,
//    according to the i2c scanner by Nick Gammon
//    https://www.gammon.com.au/forum/?id=10896
// Version 5, March 28, 2013
//    As version 4, but address scans now to 127.
//    A sensor seems to use address 120.
// Version 6, November 27, 2015.
//    Added waiting for the Leonardo serial communication.
//
//
// This sketch tests the standard 7-bit addresses
// Devices with higher bit address might not be seen properly.
//

#include <Wire.h>

void setup() {
  Wire.begin();

  Serial.begin(9600);
  while (!Serial); // Leonardo: wait for serial monitor
  Serial.println("\nI2C Scanner");
}

void loop() {
  int nDevices = 0;

  Serial.println("Scanning...");

  for (byte address = 1; address < 127; ++address) {
    // The i2c_scanner uses the return value of
    // the Write.endTransmisstion to see if
    // a device did acknowledge to the address.
    Wire.beginTransmission(address);
    byte error = Wire.endTransmission();

    if (error == 0) {
      Serial.print("I2C device found at address 0x");
      if (address < 16) {
        Serial.print("0");
      }
      Serial.print(address, HEX);
      Serial.println("  !");

      ++nDevices;
    } else if (error == 4) {
      Serial.print("Unknown error at address 0x");
      if (address < 16) {
        Serial.print("0");
      }
      Serial.println(address, HEX);
    }
  }
  if (nDevices == 0) {
    Serial.println("No I2C devices found\n");
  } else {
    Serial.println("done\n");
  }
  delay(5000); // Wait 5 seconds for next scan
}
```

LibrEars, 2021-06-25:
I made some progress. Turns out I should have used SDA0 and SDA1 from the start and then it works.

Also I found out, that the analog pins A0 and A2 are not labeled right on the board! (they need to be swaped)! I will open a new issue for that.

Also pin D7 (SCL1) and D8 (SDA1) are somehow always HIGH (missing pullup resistor?) which causes problems in my setup (not enough pins). If you for some reason need to use the SCL1 and SDA1 pins for the display (or similar) as well, I found a way :)

This is not possible by default due to missing firmware. Therefore we need to add support for the microcontroller. Here is what I did:

1. Go to the folder \Arduino\libraries and copy the folder \Grove_-_LCD_RGB_Backlight and rename it to \Grove_-_LCD_RGB_Backlight_Serial1
2. In the Folder \Grove_-_LCD_RGB_Backlight_Serial1 rename the files rgb_lcd.cpp and rgb_lcd.h to rgb_lcd1.cpp and rgb_lcd1.h
3. Open the file rgb_lcd1.cpp with an text editor and change the lines  #include <Wire.h> to #include <Wire1.h> #include "rgb_lcd.h" to #include "rgb_lcd1.h"
Also add the line
extern TwoWire1 Wire1; // insert this line is the modification to include Wire1 (SDA1 / SCL1) .…
    5. Then press ‘Ctrl+h’  to replace all function calls starting with Wire.xxx() with Wire1.xxx()
! Make sure to not replace the lines added above a second time
    6. From now on in the arduino code always include #include <Wire1.h> and #include "rgb_lcd1.h"

Sources:
    • https://github.com/MCUdude/MiniCore This lib adds support for the  ATmega328PB, in detail for serial communication with the lib Wire1.h
    • https://www.instructables.com/How-to-share-i2C-connection-on-Due/ To get the display running, we need to change its lib rgb_lcd.h

LibrEars, 2021-06-25:
https://github.com/uStepper/uStepperS/issues/35

uStepper, 2023-08-13:
We will correct the silk on any future revisions of S. The high level on D7 and D8 is caused by pull-up resistors for the i2c.

Closed 2023-08-13.

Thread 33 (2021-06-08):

Spurious change to DDRB port in uStepperS::setup

thekeeno, 2021-06-08:
In line 269 of uStepperS.cpp, we have:

`/DDRB |= (1 << 4);`

 It sets the data direction on pin 4 of port B as output. This is the MISO0/RXD1 pin, which is not used by the driver or the encoder and should, in principle, be user configurable.

This line seems spurious and actually interferes with some other libraries when used on the uStepperS. The line in question does not seem to serve any purpose to the uStepper - so I suggest it be removed.

uStepper, 2023-10-07:
Fixed in release 2.3.2

Closed 2023-10-07.

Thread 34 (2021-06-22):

Motor holding will sometimes turn off after stepping

BeebBenjamin, 2021-06-22:
Sometimes after stepping forward a few times, the hold will click off then come back on and get into a state where it toggles until the usteper is restarted.  Do you know what might be causing this? Here is my code:

```
#include <uStepperS.h>

  uStepperS stepper;

  int angle = 10;
  int angles[] = {360, 180, 120, 90, 72, 60, 45, 40, 36, 30, 24, 20, 18, 15, 12, 10, 9, 8, 6, 5, 4, 3, 2, 1};
  int cmd;
  int angle_index = 15;

  void setup() {
    stepper.setup(NORMAL,200,0,0,0,16,false, 0,80,80);
    stepper.setMaxAcceleration(5);
    stepper.setMaxVelocity(250);
    stepper.setBrakeMode(FREEWHEELBRAKE);
    Serial.begin(9600);
  }

  void loop() {
    if (Serial.available() > 0) {
      cmd = Serial.read() - '0';

      switch(cmd){
        case 0:
          stepper.setBrakeMode(HARDBRAKE, 80);
          while(stepper.getMotorState()== 1);
          Serial.write(6);
          break;
        case 1:
          stepper.moveAngle(angle);
          stepper.setBrakeMode(HARDBRAKE, 80);
          while(stepper.getMotorState()== 1);
          Serial.write(6);
          break;
        case 2:
          stepper.moveAngle(-angle);
          stepper.setBrakeMode(HARDBRAKE, 80);
          while(stepper.getMotorState()==1);
          Serial.write(6);
          break;
        case 3:
          stepper.stop();
          stepper.setBrakeMode(FREEWHEELBRAKE);
          break;
        case 4:
          if (angle_index == 23){
            angle_index = 0;
          }
          if (angle_index < 23){
            angle_index = angle_index + 1;
          }
          angle = angles[angle_index];
          break;
        case 5:
          if (angle_index == 0){
            angle_index = 23;
          }
          if (angle_index >  0){
            angle_index = angle_index - 1;
          }
          angle = angles[angle_index];
          break;
      }
    }
  }

BeebBenjamin, 2021-06-23:
Tested on the following code changes:

```
#include <uStepperS.h>

uStepperS stepper;

int angle = 10;
int angles[] = {360, 180, 120, 90, 72, 60, 45, 40, 36, 30, 24, 20, 18, 15, 12, 10, 9, 8, 6, 5, 4, 3, 2, 1};
int cmd;
int angle_index = 15;

void setup() {
  stepper.setup(NORMAL,200,0,0,0,16,false, 0,80,80);
  stepper.setMaxAcceleration(5);
  stepper.setMaxVelocity(250);
  stepper.setBrakeMode(FREEWHEELBRAKE);
  Serial.begin(9600);
}

void loop() {
  if (Serial.available() > 0) {
    cmd = Serial.read() - '0';

    switch(cmd){
      case 0:
        stepper.setBrakeMode(HARDBRAKE, 80);
        Serial.write(6);
        break;
      case 1:
        stepper.moveAngle(angle);
        while(stepper.getMotorState()== 1);
        stepper.setBrakeMode(HARDBRAKE, 80);
        Serial.write(6);
        break;
      case 2:
        stepper.moveAngle(-angle);
        while(stepper.getMotorState()==1);
        stepper.setBrakeMode(HARDBRAKE, 80);
        Serial.write(6);
        break;
      case 3:
        stepper.stop();
        stepper.setBrakeMode(FREEWHEELBRAKE);
        Serial.write(6);
        break;
      case 4:
        if (angle_index == 23){
          angle_index = 0;
        }
        if (angle_index < 23){
          angle_index = angle_index + 1;
        }
        angle = angles[angle_index];
        Serial.write(6);
        break;
      case 5:
        if (angle_index == 0){
          angle_index = 23;
        }
        if (angle_index >  0){
          angle_index = angle_index - 1;
        }
        angle = angles[angle_index];
        Serial.write(6);
        break;
    }
  }
}

The ustepper goes into an unresponsive state after sitting idle, and cycles between the motor engaged or off.  It happens when I run the serial link through the Arduino IDE and when I am using Python Serial.

BeebBenjamin, 2021-06-23:
Update: I can stop the cycle by sending a 1 or a 2 to turn the motor, but it will once again go into cycling on and off after sitting idle with the break on for a short while.

BeebBenjamin, 2021-06-24:
I do wonder if I am seeing this manifest: https://github.com/uStepper/uStepperS/issues/7 so I have lowered the current to 50% and am doing some tests.

uStepper, 2023-08-13:
As you indicate on the last post, active cooling or lower current settings is required for "long" time braking.

Closed 2023-08-13.

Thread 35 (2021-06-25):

Analog pins A0 and A2 labels are exchanged (A0 should be A2 and vice versa)

LibrEars, 2021-06-25:
Hi,

on my board I noticed that the analog pins A0 and A2 are exchanged (A0 should be A2 and vice versa). The labels in the product sheet are wrong (also in the schematics) and on the bord. The serial ports SCL0 and SCL1 are labeled right on the other hand.

Maybe this has something to do with the upgrade from ATmega328P to ATmega328P**B**?

uStepper, 2023-08-13:
fixed in release 2.2.4

Closed 2023-08-13.

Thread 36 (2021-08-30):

Motor starts moving after 'setMaxVelocity' is set.

Daniel-Walther, 2021-08-30:
**Bug at 2.2.1 version:**

After stopping the moter by 'uStepperS.stop(HARD)' or 'uStepperS.stop(SOFT)' the motor starts immediately runing at the next 'uStepperS.setMaxVelocity(XXX)' command.

**Example:**

```cpp
#include <uStepperS.h>
uStepperS stepper;
void setup()
{
	stepper.setup();
	stepper.checkOrientation(30.0);
	MoveHome(false);
	stepper.stop(SOFT);
	stepper.setMaxVelocity(1000); //-->here motor starts to move
}
```

**Attempt to explain:**
The 'stop' method at the uStepperS code only sets the target speed to zero. But the target-position register is not set. Then changing the velocity to a none-zero value the driver starts to moving to the value which is set to the target position register.

**Workaraound:**
The 'stop' method at the uStepperS code should wait until the motor realy stops movement. After that, the target position should set to the current position:

**ORIGINAL CODE:**
```cpp
void uStepperS::stop( bool mode){
	if(mode == HARD)
	{
		this->driver.setDeceleration( 0xFFFE );
		this->driver.setAcceleration( 0xFFFE );
		this->setRPM(0);
		while(this->driver.readRegister(VACTUAL) != 0);
		this->driver.setDeceleration( (uint32_t)( this->maxDeceleration ) );
		this->driver.setAcceleration( (uint32_t)(this->maxAcceleration ) );
	}
	else
	{
		this->setRPM(0);
	}
}
```

**WORKAROUND CODE:**
```cpp
void uStepperS::stop( bool mode){
	if(mode == HARD)
	{
		this->driver.setDeceleration( 0xFFFE );
		this->driver.setAcceleration( 0xFFFE );
		this->setRPM(0);
		while(this->driver.readRegister(VACTUAL) != 0);
		this->driver.setDeceleration( (uint32_t)( this->maxDeceleration ) );
		this->driver.setAcceleration( (uint32_t)(this->maxAcceleration ) );
	}
	else
	{
		this->setRPM(0);
		while(this->driver.readRegister(VACTUAL) != 0);
	}
	// Get current position
	int32_t current = this->driver.getPosition();
	// Set new position
	this->driver.setPosition( current );
}
```

uStepper, 2023-08-13:
Change implemented in latest release

Closed 2023-08-13.

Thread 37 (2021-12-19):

USB Communication with HOST PC

andybee909, 2021-12-19:
Hi! I am using uStepperS instead of an Arduino Uno + PWM Motor. The uStepperS should
receive informations via USB 115.200 Baud. When I start the communication between uStepper and PC Software,
it does a reset on the uStepper. With Arduino Uno, everything works fine. Is for the ustepper another commonication library needed?
As far as I noticed, the uStepperS uses mostly the same CPU as Arduino Uno? (Atmega328)
Pins D0 and D1 are not in use because of RX0/TX0 (USB).
I also have noticed, the uStepper uses a Atmega328PB, which is a bit different...
Thanks for your support! Have a nice sunday evening ;)

uStepper, 2023-08-13:
It is only on port opening the MCU will reset which is caused by the intentional hardware solution made around the USB chip.

Closed 2023-08-13.

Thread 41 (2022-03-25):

Random jerking on startup.

Bumraider, 2022-03-25:
Hi

good day, one day to another upon booting up my marlin based printer the ustepper for a single axis has begun behaving erratically.

I have altered the PID parameters, setup in dropin mode and values for P ,I , D are 0.1 ,0,1 and 0 respectively.

This minimizes the random jerking motions intensity however still randomly jerks back and forth.

I have read in previous posts that reducing the holding and driving motor current percentages below 50 % might help solve, but no change has been witnessed.

As it has only occurred on a single motor (x axis) with equivalent code as the y axis. I am suspecting the ustepper may be defective.

I have also checked that the magnet sits flush on the surface of the stepper motor

Please instruct me how to proceed

Closed 2022-03-29.

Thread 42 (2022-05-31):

i2c not working in latest board update

tombankz, 2022-05-31:
Latest update 2.2.3 seems to break i2c communication. I spent hours only to find the solution was to downgrade to 2.2.2 and it fixed it.

uStepper, 2022-06-01:
Hi tom,

Thank you for your message. it was a small error in the pin definition file, and it have been corrected now in the new release (2.2.4)

Closed 2022-06-01.

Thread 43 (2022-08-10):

Platform support for vs code platform io

smukkejohan, 2022-08-10:
Has there been any work adding support for the ustepper through vscode with platform io.

I know lots of people are using that as their preferred IDE in favor of the rather minimal arduino IDE.

Happy to help look into it, maybe someone is already on to it?

smukkejohan, 2022-08-10:
Opened a request here: https://github.com/platformio/platformio-core/issues/4387

uStepper, 2022-08-16:
Hi Johan,

We have not been looking into adding support for platform io.

If you are willing to look into it, it would be much appreciated ! :)

Closed 2023-08-13.

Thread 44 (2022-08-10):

Encoder stall examples broken

smukkejohan, 2022-08-10:
The examples for the encoder stall does not compile on my setup. Using uStepper 2.2.4 in boards  and uStepper S 2.3.1 in libraries. Arduino IDE 1.8.19 on macOS 12.4.

Reports following errors:

```
EncoderStall.ino: In function 'void setup()':
EncoderStall:56:11: error: 'class uStepperEncoder' has no member named 'encoderStallDetectSensitivity'
   stepper.encoder.encoderStallDetectSensitivity = -0.25;//Encoder stalldetect sensitivity - From -10 to 1 where lower number is less sensitive and higher is more sensitive. -0.25 works for most.
EncoderStall:57:11: error: 'class uStepperEncoder' has no member named 'encoderStallDetectEnable'
   stepper..encoder.encoderStallDetectEnable = 1; //Enable the encoder stall detect
EncoderStall.ino: In function 'void loop()':
EncoderStall:61:32: error: 'class uStepperEncoder' has no member named 'encoderStallDetect'; did you mean 'encoderFilter'?
   bool stall = stepper.encoder.encoderStallDetect;//Read the stall decision
```

```
EncoderStallSensitivityCalibration.ino: In function 'void setup()':
EncoderStallSensitivityCalibration:56:19: error: 'class uStepperEncoder' has no member named 'encoderStallDetectEnable'
   stepper.encoder.encoderStallDetectEnable = 1; //Enable the encoder stall detect
EncoderStallSensitivityCalibration.ino: In function 'void loop()':
EncoderStallSensitivityCalibration:69:23: error: 'class uStepperEncoder' has no member named 'encoderStallDetectSensitivity'
       stepper.encoder.encoderStallDetectSensitivity = 1-(stallValue*0.05);
EncoderStallSensitivityCalibration:71:27: error: 'class uStepperEncoder' has no member named 'encoderStallDetect'; did you mean 'encoderFilter'?
       if(!stepper.encoder.encoderStallDetect)

```

uStepper, 2023-10-07:
Fixed in release 2.3.2

Closed 2023-10-07.

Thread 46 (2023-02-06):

Add board footprint

kriskeillor, 2023-02-06:
Hello,
I am developing a shield for the uStepper S that adds bluetooth functionality. It would be very helpful to have a complete, dimensioned footprint of the uStepper S and uStepper S-Lite (if there's any difference, e.g. reset button placement) to properly align the headers on my shield.

As it stands, the only information I can find is the overall size and hole placement (41.8mm and 36mm, respectively).

Information about the three headers is necessary. For folks integrating enclosures, the button and power/USB port placements would also be helpful.

Thank you!

uStepper, 2023-02-08:
Hi Kris,

I have attached a step file of the uStepper S pcb here. the connector and hole placement are identical for the S-lite
[uStepper.zip](https://github.com/uStepper/uStepperS/files/10689869/uStepper.zip)

I hope this helps !

Best Regards,
Thomas Olsen

uStepper, 2023-02-13:
Hi,A step model with precise dimensions is available here:uStepperS/Hardware at master · uStepper/uStepperSgithub.comBest regards, MogensDen 6. feb. 2023 kl. 22.41 skrev Kris Keillor ***@***.***>:
Hello,
I am developing a shield for the uStepper S that adds bluetooth functionality. It would be very helpful to have a complete, dimensioned footprint of the uStepper S and uStepper S-Lite (if there's any difference) to properly align the headers on my shield.
As it stands, the only information I can find is the overall size and hole placement (41.8mm and 36mm, respectively).
Information about the three headers is necessary. For folks integrating enclosures, the button and power/USB port placements would also be helpful.
Thank you!

—Reply to this email directly, view it on GitHub, or unsubscribe.You are receiving this because you are subscribed to this thread.Message ID: ***@***.***>

kriskeillor, 2023-02-19:
Hi Thomas,

Thank you for sharing that!

I was aware of the step file. I don't currently have access to, or skill with, a 3d modeling program that can quickly tell me the dimensions. A board outline meant for use with typical electrical schematic capture programs (Altium and KiCad would be a great start) would be a blessing for electrical engineers with less mechanical aptitude.

Fortunately, I got pretty accurate measurements using a digital caliper.

Again thank you for the helpful reply!
Best,
Kris

Closed 2023-02-19.

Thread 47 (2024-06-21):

Config UstepperS in Klipper

beppexx80, 2024-06-21:
Hi,
Is it possible to have a basic configuration to make UstepperS work in klipper?
Thank you

zenpai45, 2024-06-26:
Hi,

Since the uStepper S uses a common AVR MCU, it should be possible to flash klipper onto it. however, we do not have the time or ressources to implement this currently.

Best Regards,
Thomas Olsen

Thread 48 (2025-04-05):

uStepper S - How to recover after an encoder detected stall ?

TimTheEngineer, 2025-04-05:
I can't figure out how to recover from encorder stall ? the example works exactly as expected, stopping the motor on stall detect. There must be something that needs clearing/resetting in order to restart ? Ive removed the while(1) inifinte loop from the encoderStall example and added

`stepper.encoder.encoderStallDetect = 0;
    stepper.setup();
    stepper.checkOrientation(10.0);
    stepper.setRPM(100);`

This has no effect other than to give a little wiggle from the checkOrientation.

stepper.reset() had no effect
stepper.clearStall()  had no effect - but this is for stallguard stalls, so thats no surprise.

TimTheEngineer, 2025-06-02:
stallguard appeaers to be very sensitive to minor changes in the snsitivity, with 2 resulting in stall detect before end of stroke, and 4 resulting in hitting end of stroke and not detecting the stall. Thats why I wanted to give the encoder based stall detection a try ! Sadly, whilst it is more reliable at detecting stall, I can't find any way to re-enable the motor.

TimTheEngineer, 2025-06-02:
Once stalled, stepper.encoder.encoderStallDetect always is set to 1, which indicates a stall. It never returns to zero and allows the motor to run.

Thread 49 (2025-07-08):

stepper.getMotorState() doesnt appear to work as expected ?

TimTheEngineer, 2025-07-08:
I expected POSITION_REACHED should be true when the current position = the target position ?
equally, if the motor is not moving I expected STANDSTILL to be true ?

neither appear ever to be true ?

Its not entirely clear how these are supposed to work ?

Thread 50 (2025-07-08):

Is it OK to update stepper.driver.xTarget with new data before the previous move has eneded ?

TimTheEngineer, 2025-07-08:
If the target position is updated, will tbe motor move profile be updated to reflect the chane (reversing if necessary)

I know its lazy, but this would be easier than calling for a stop, waiting for the stop and then requesting a new move.

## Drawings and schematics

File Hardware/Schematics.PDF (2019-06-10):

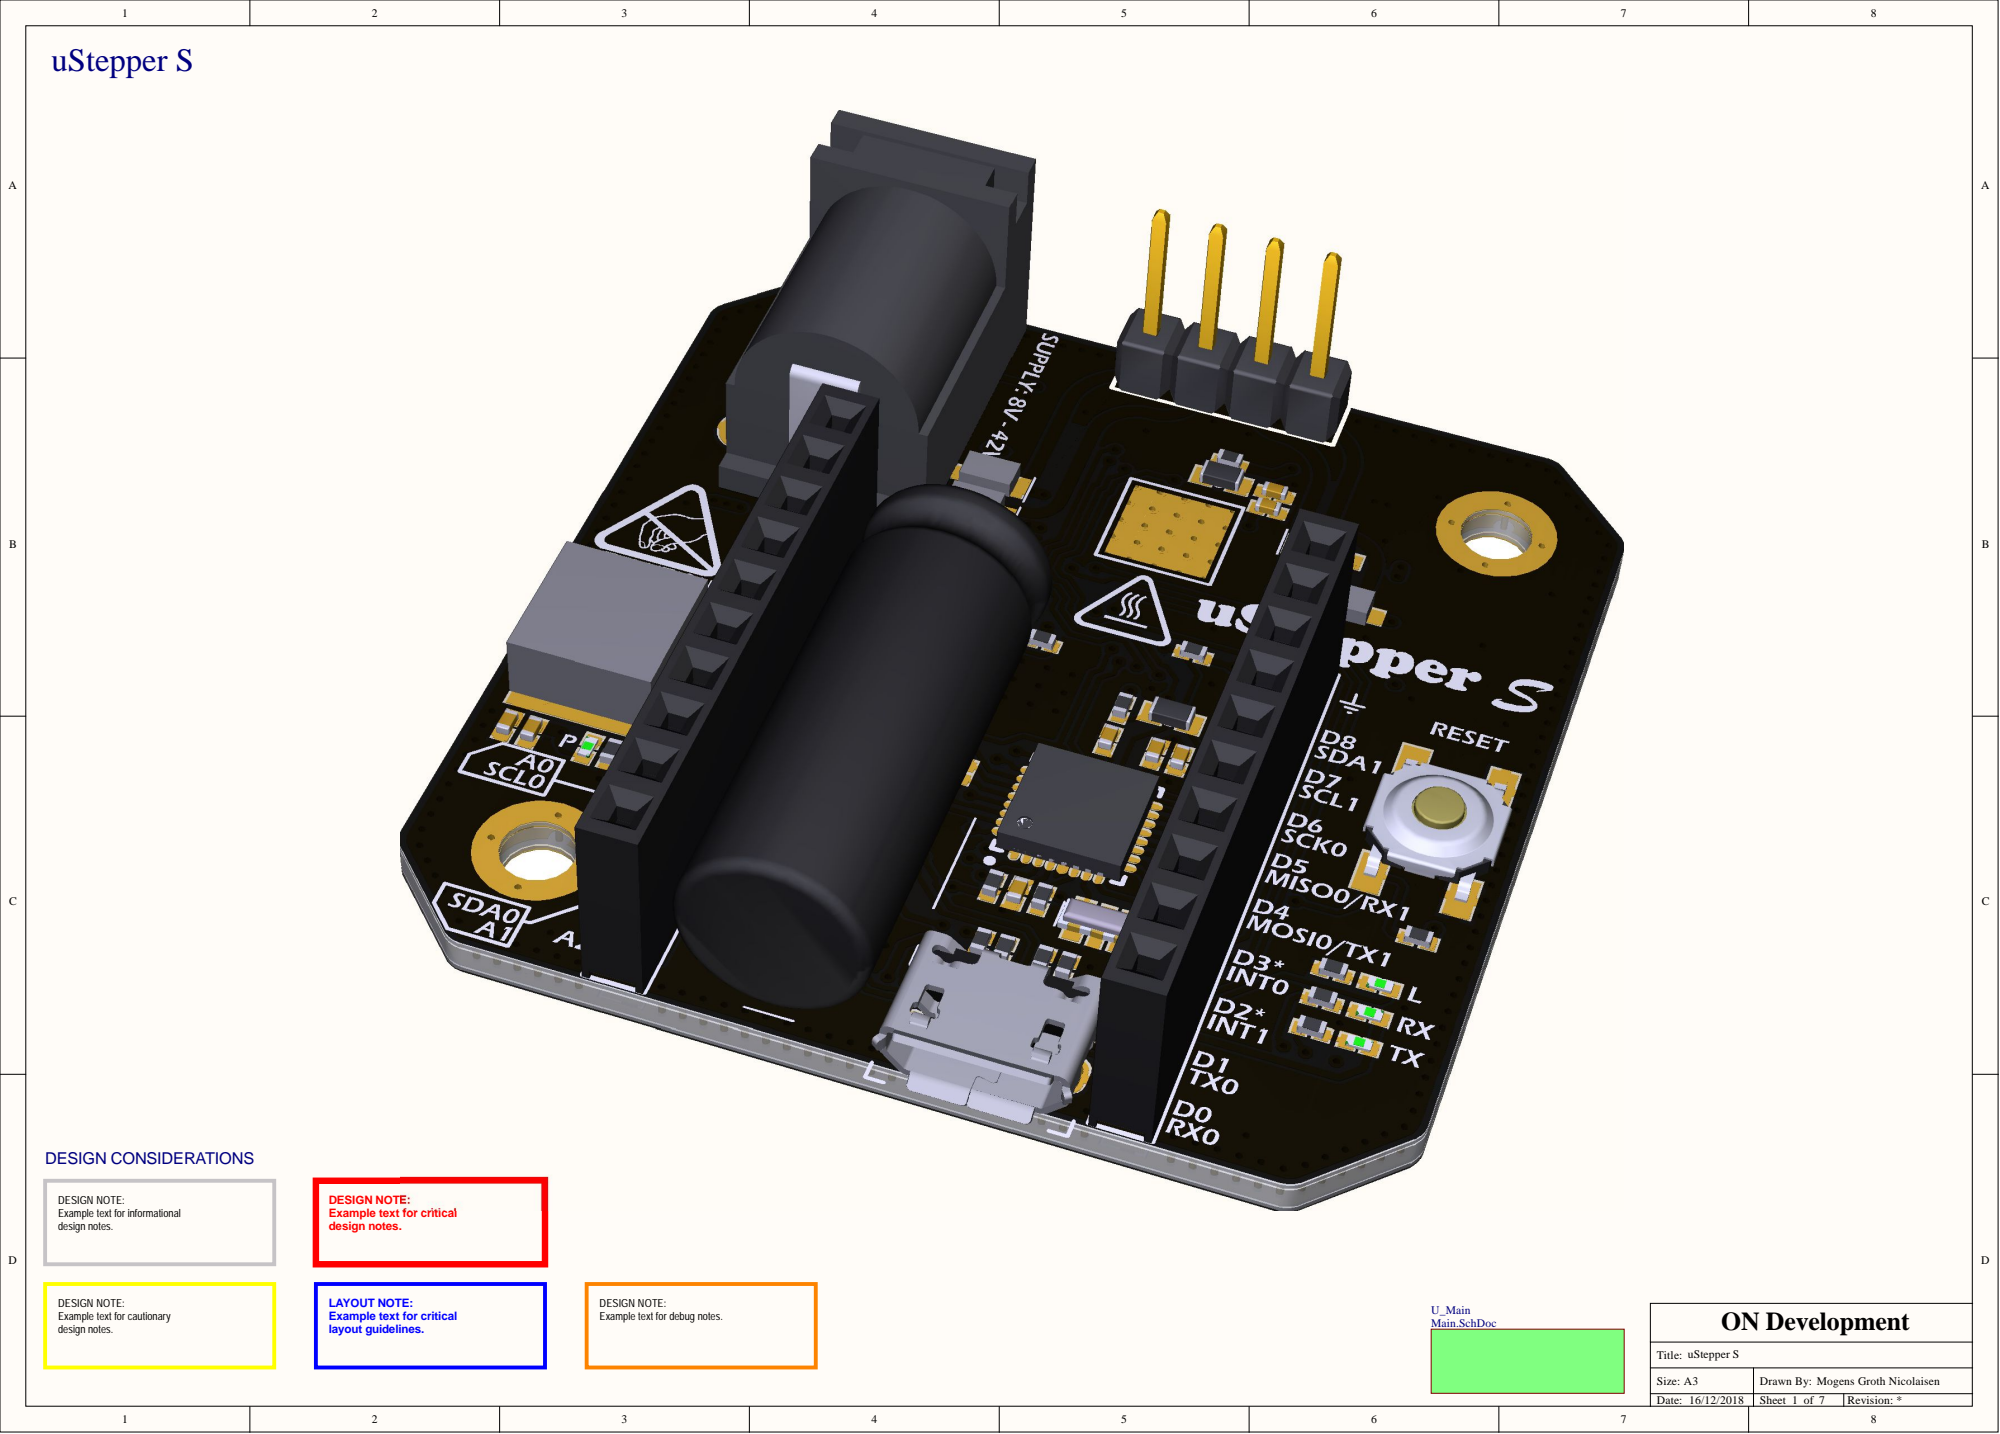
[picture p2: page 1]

DESIGN NOTE:
Example text for informational
design notes.

Example text for critical

Example text for cautionary

LAYOUT NOTE:
layout guidelines.

Size: A3 | Drawn By: Mogens Groth Nicolaisen
Date: 16/12/2018 | Sheet 1 of 7 | Revision: *

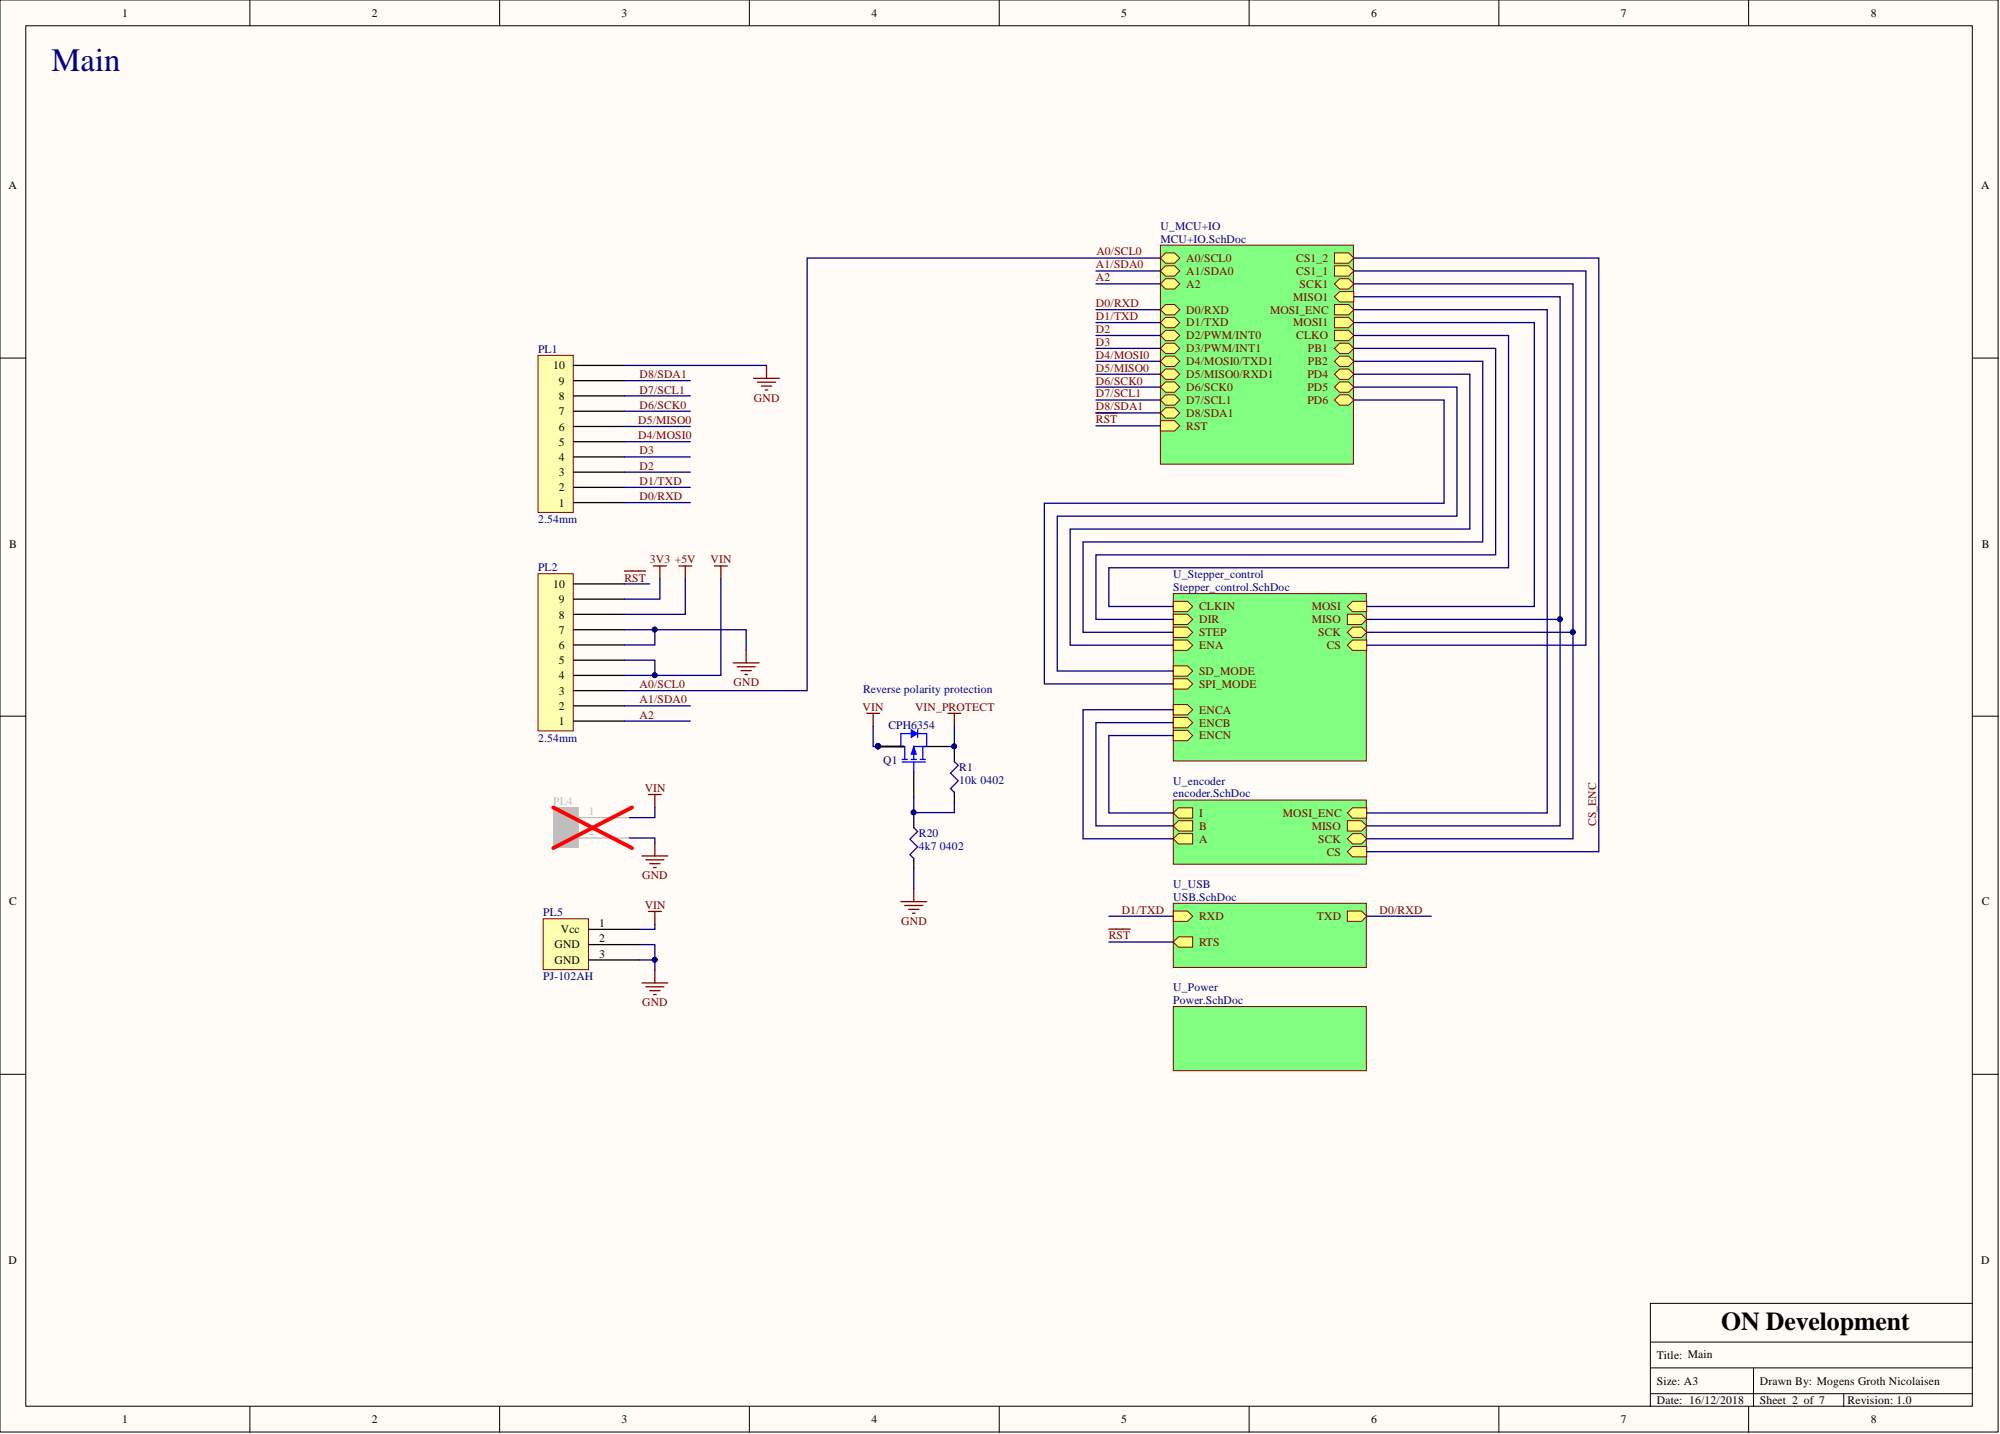
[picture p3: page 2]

D 6 /SCK 0 D 8 /SD A 1
D 5 /MISO 0 RST

U _Step per_co n tro l Step per_co n tro l.Sch D o c

CL KIN MOSI DIR MISO ST E P SCK E N A CS SD _MO D E SPI_MO D E E NCA E NCB E NCN

U _enco der enco der.Sch D o c

Size: Date: A | Sheet Draw n By : Mo gen s Gro h N ico lai sen

/ | o f | Rev s n :

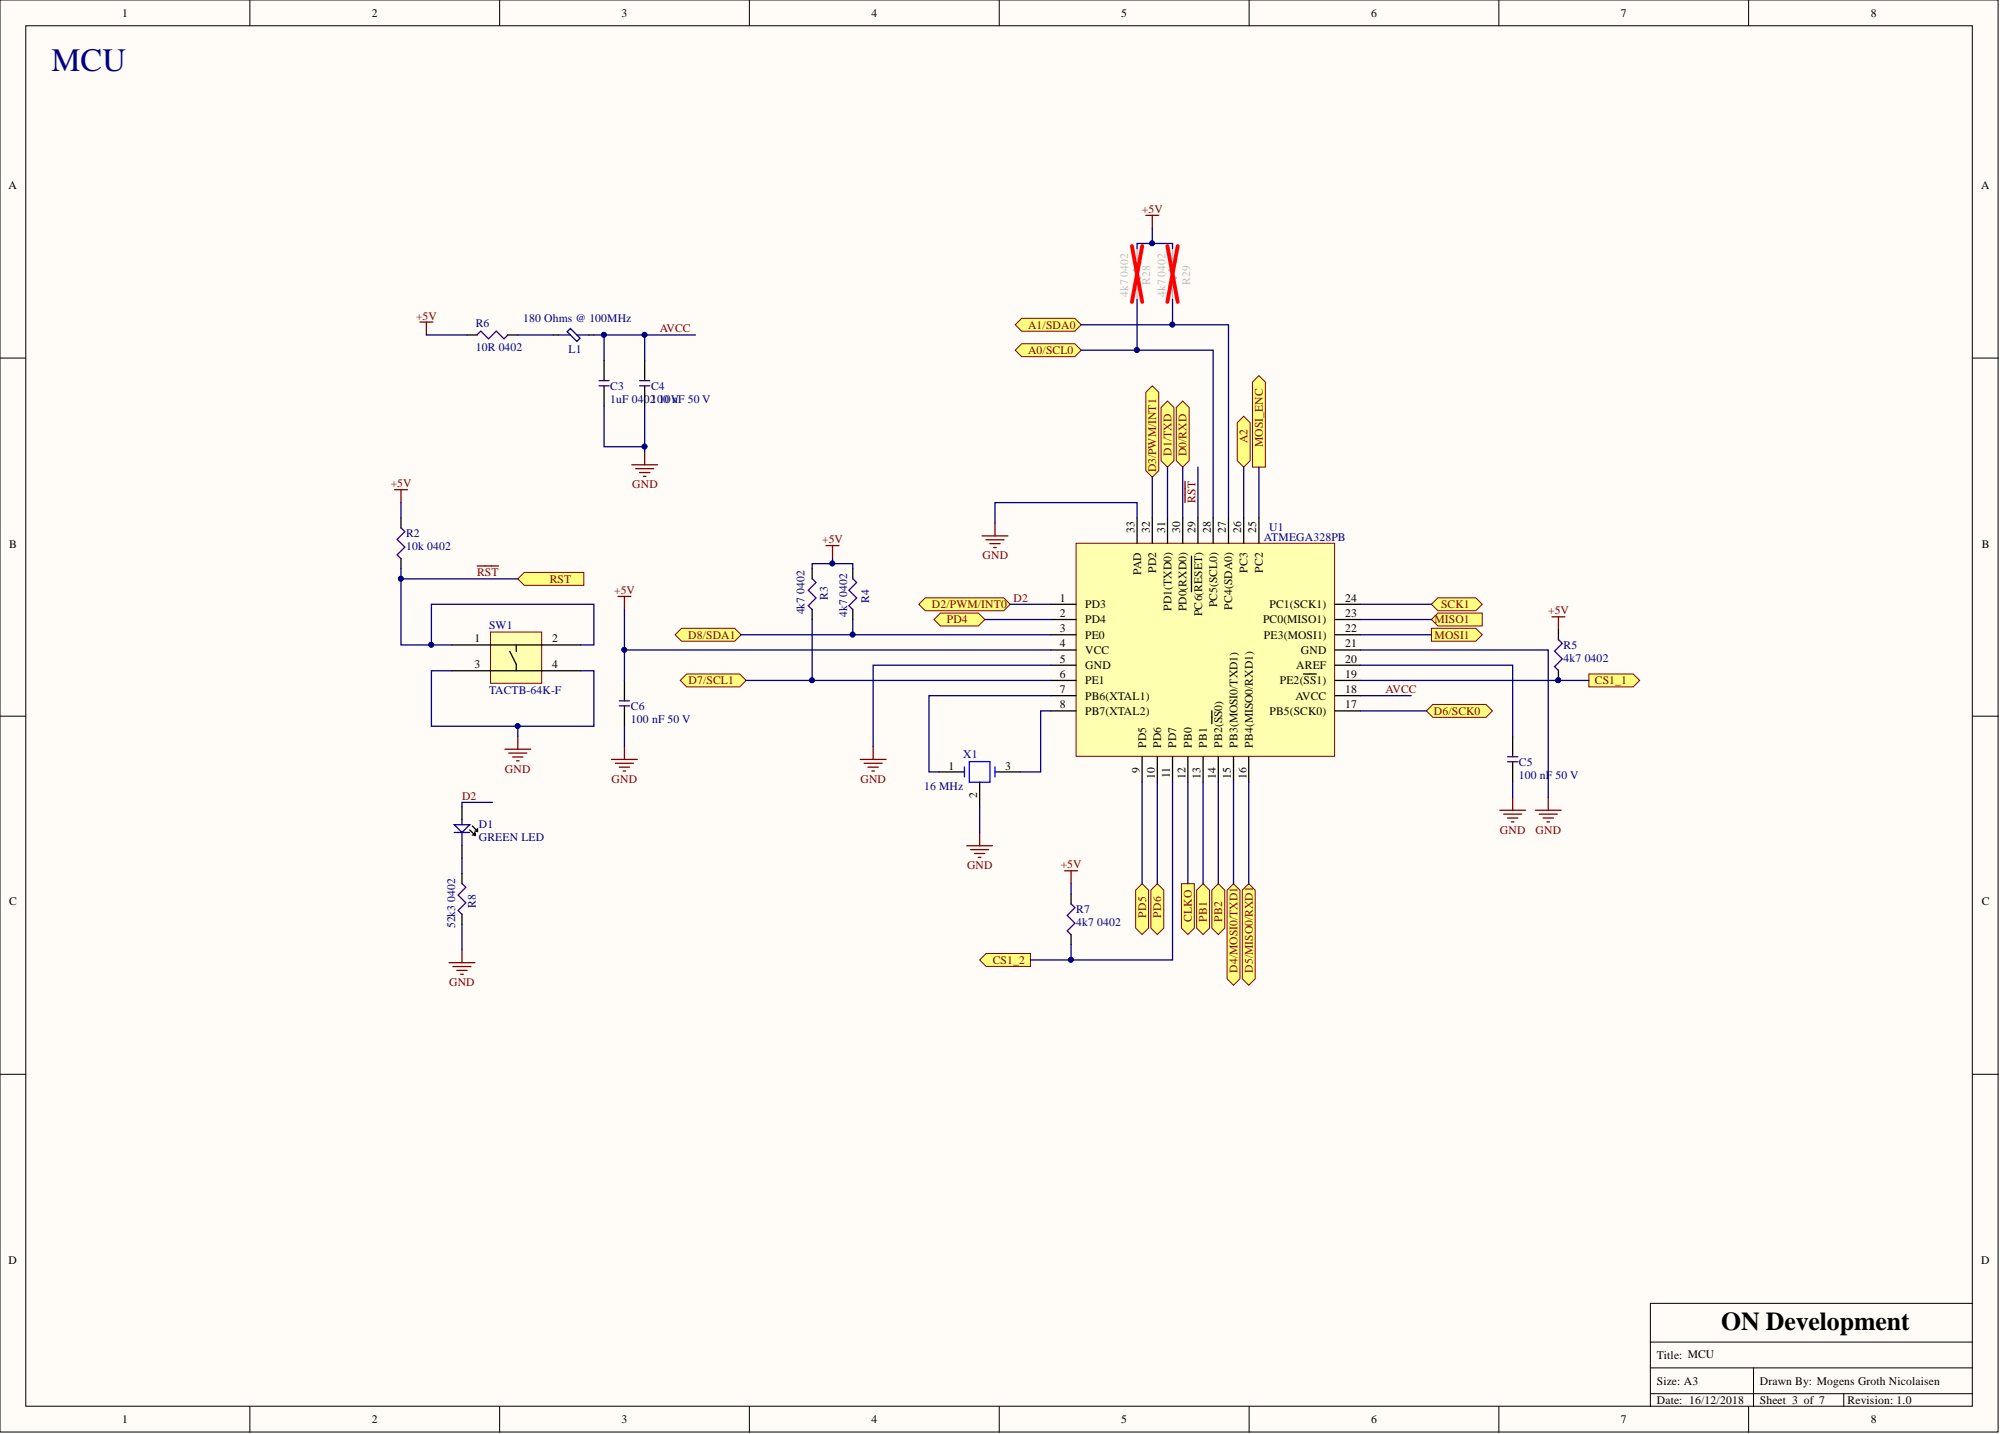
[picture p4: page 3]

PE1 6 | | AVCC D6/SCK0

PB7(XTAL2) 8

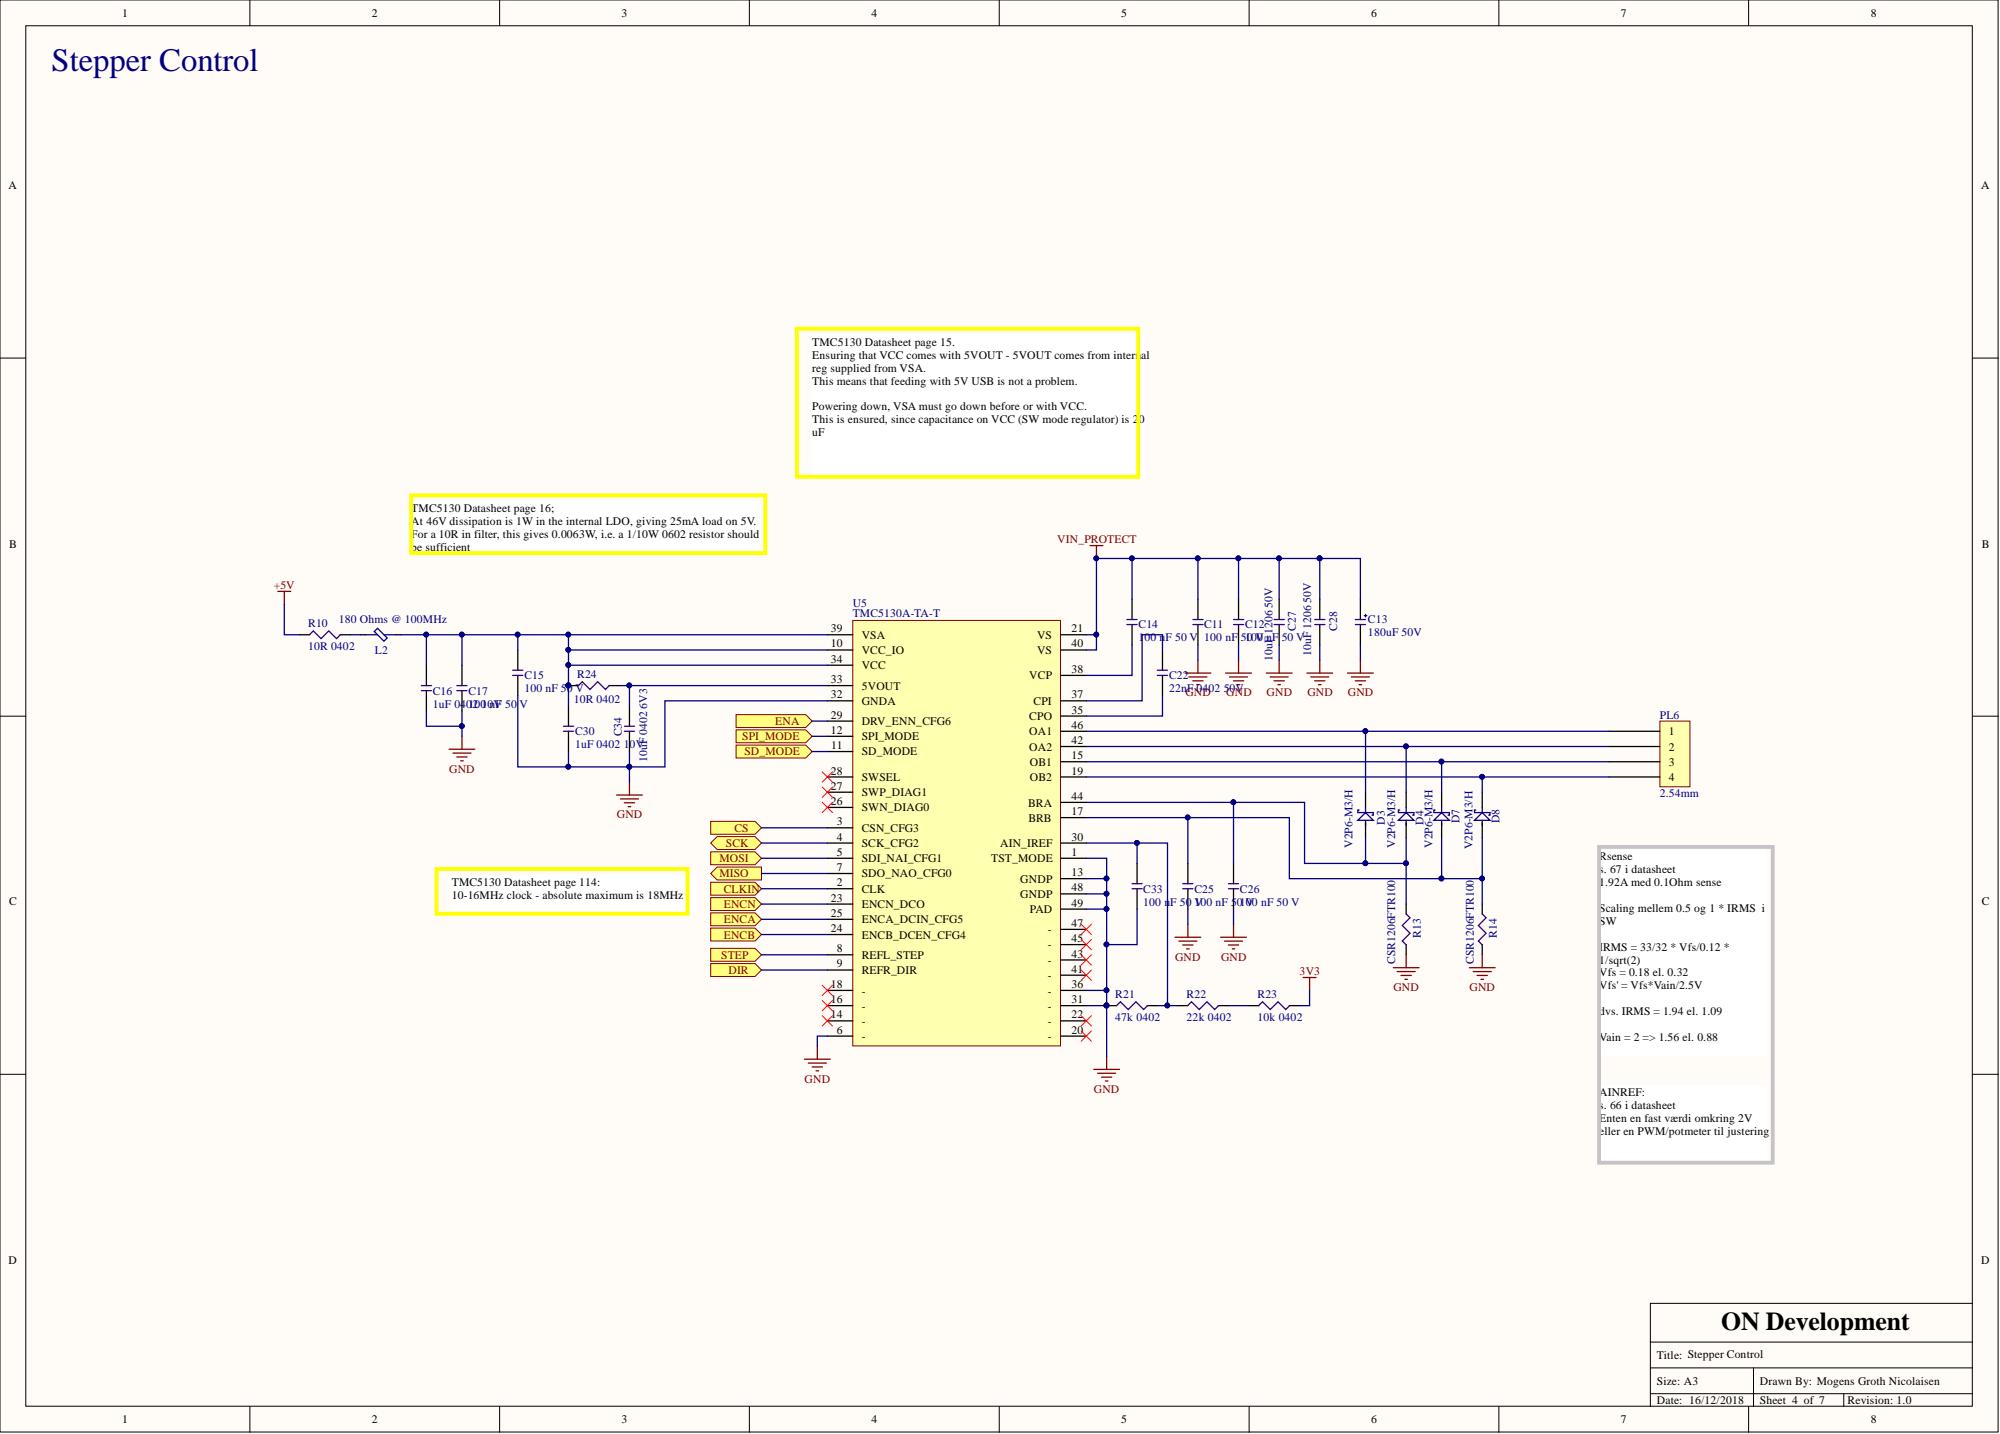
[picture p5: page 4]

E N A SPI_MO D E V SD _MO D E | 2 9 | 3 5

1 5
1 9

3 0

4 9
4 7

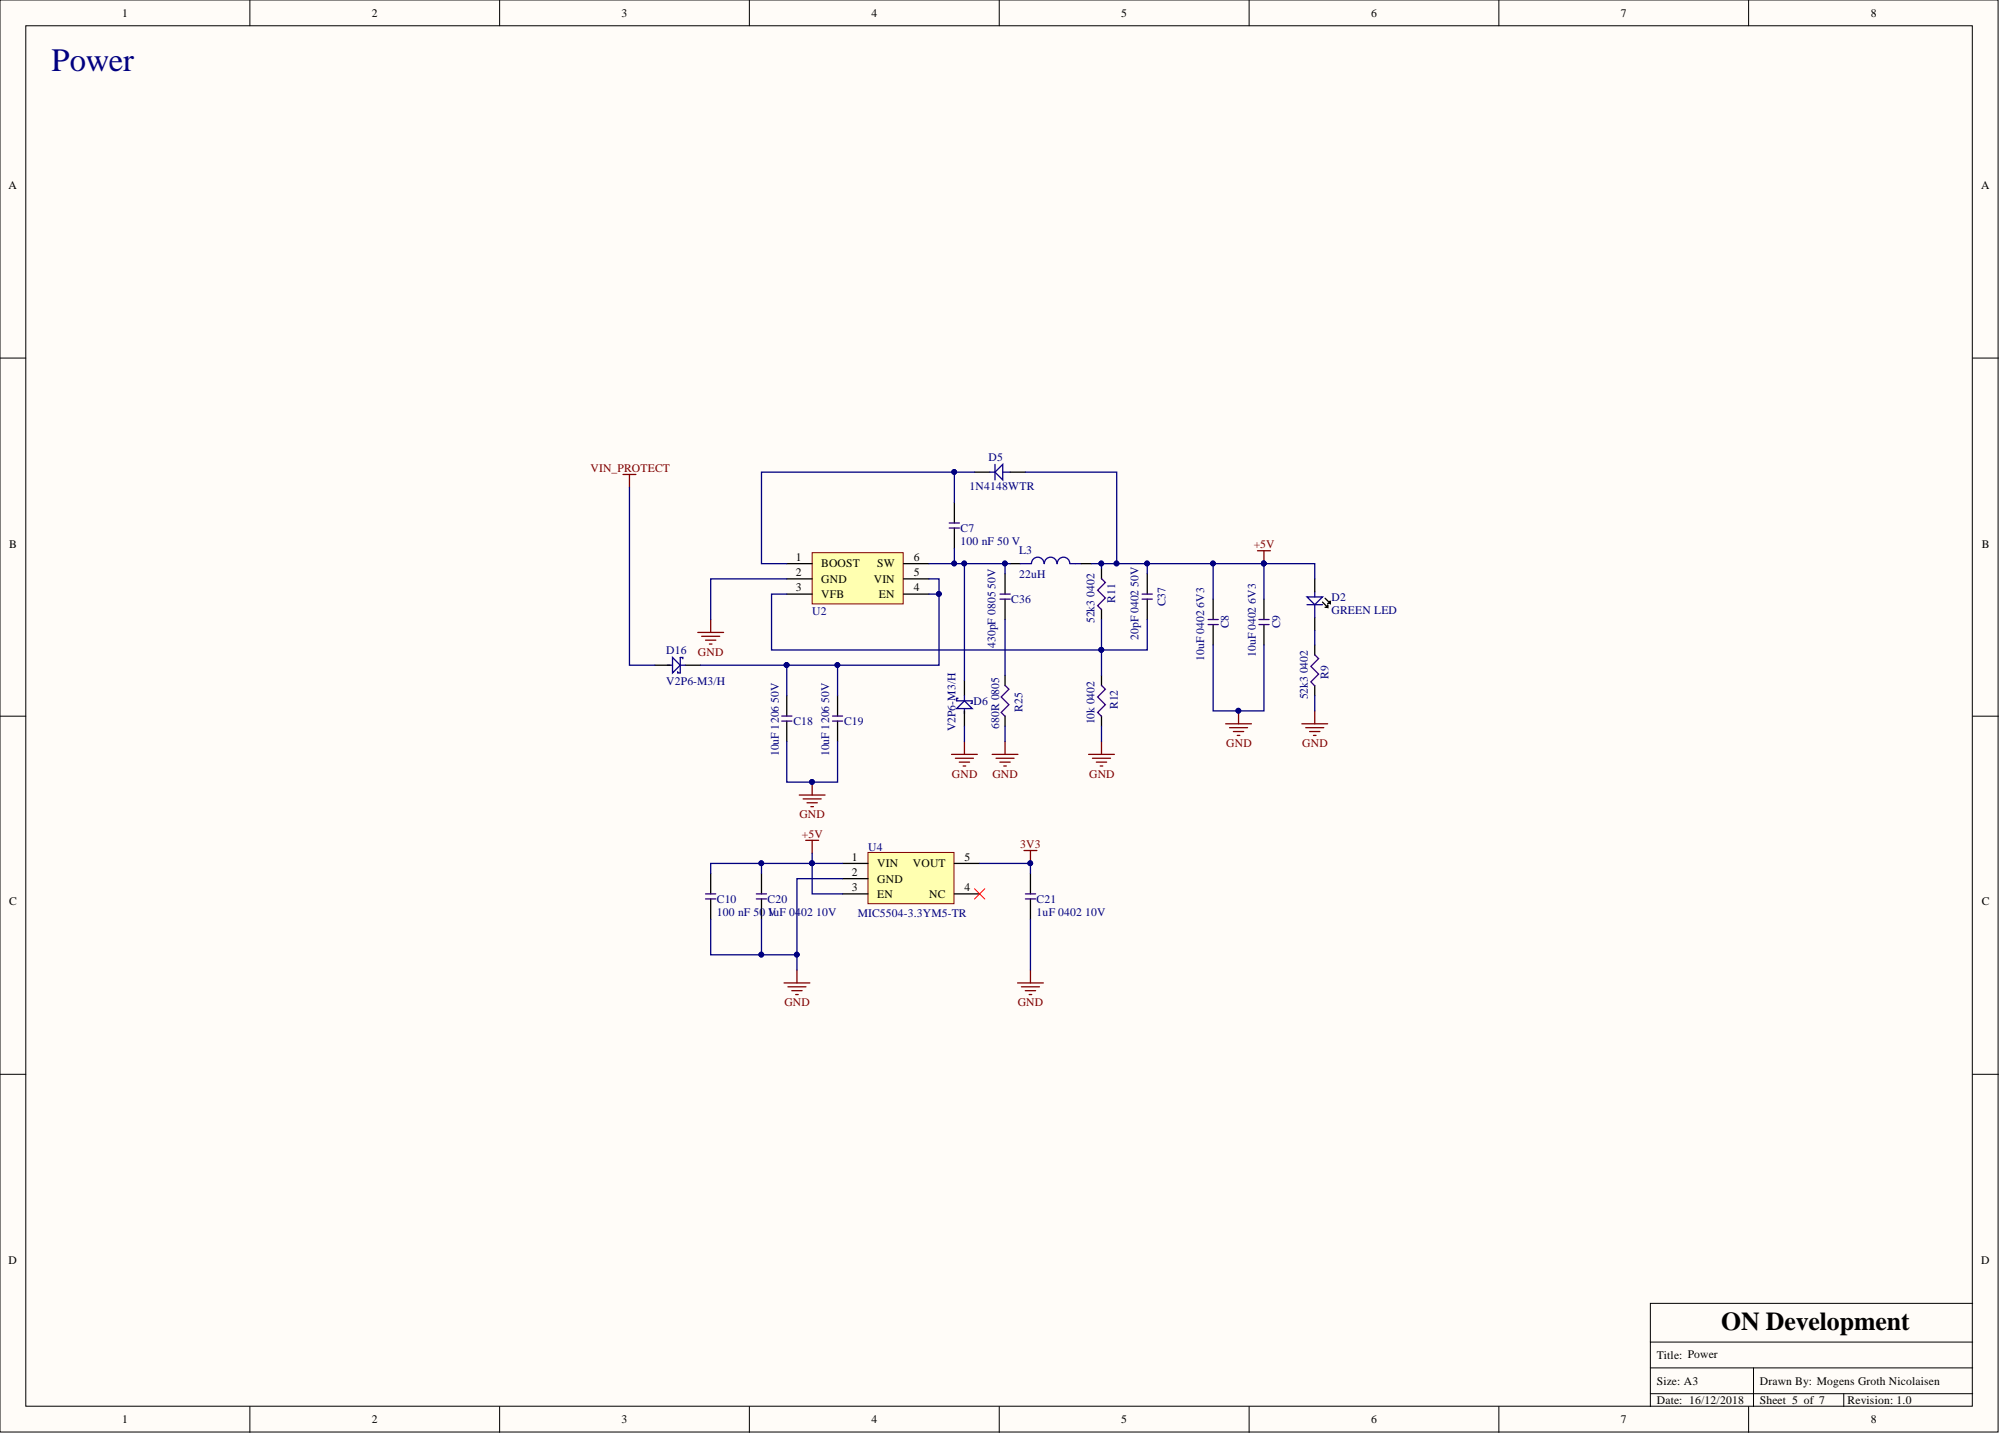
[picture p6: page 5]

GND 2 VIN | 5
VFB 3

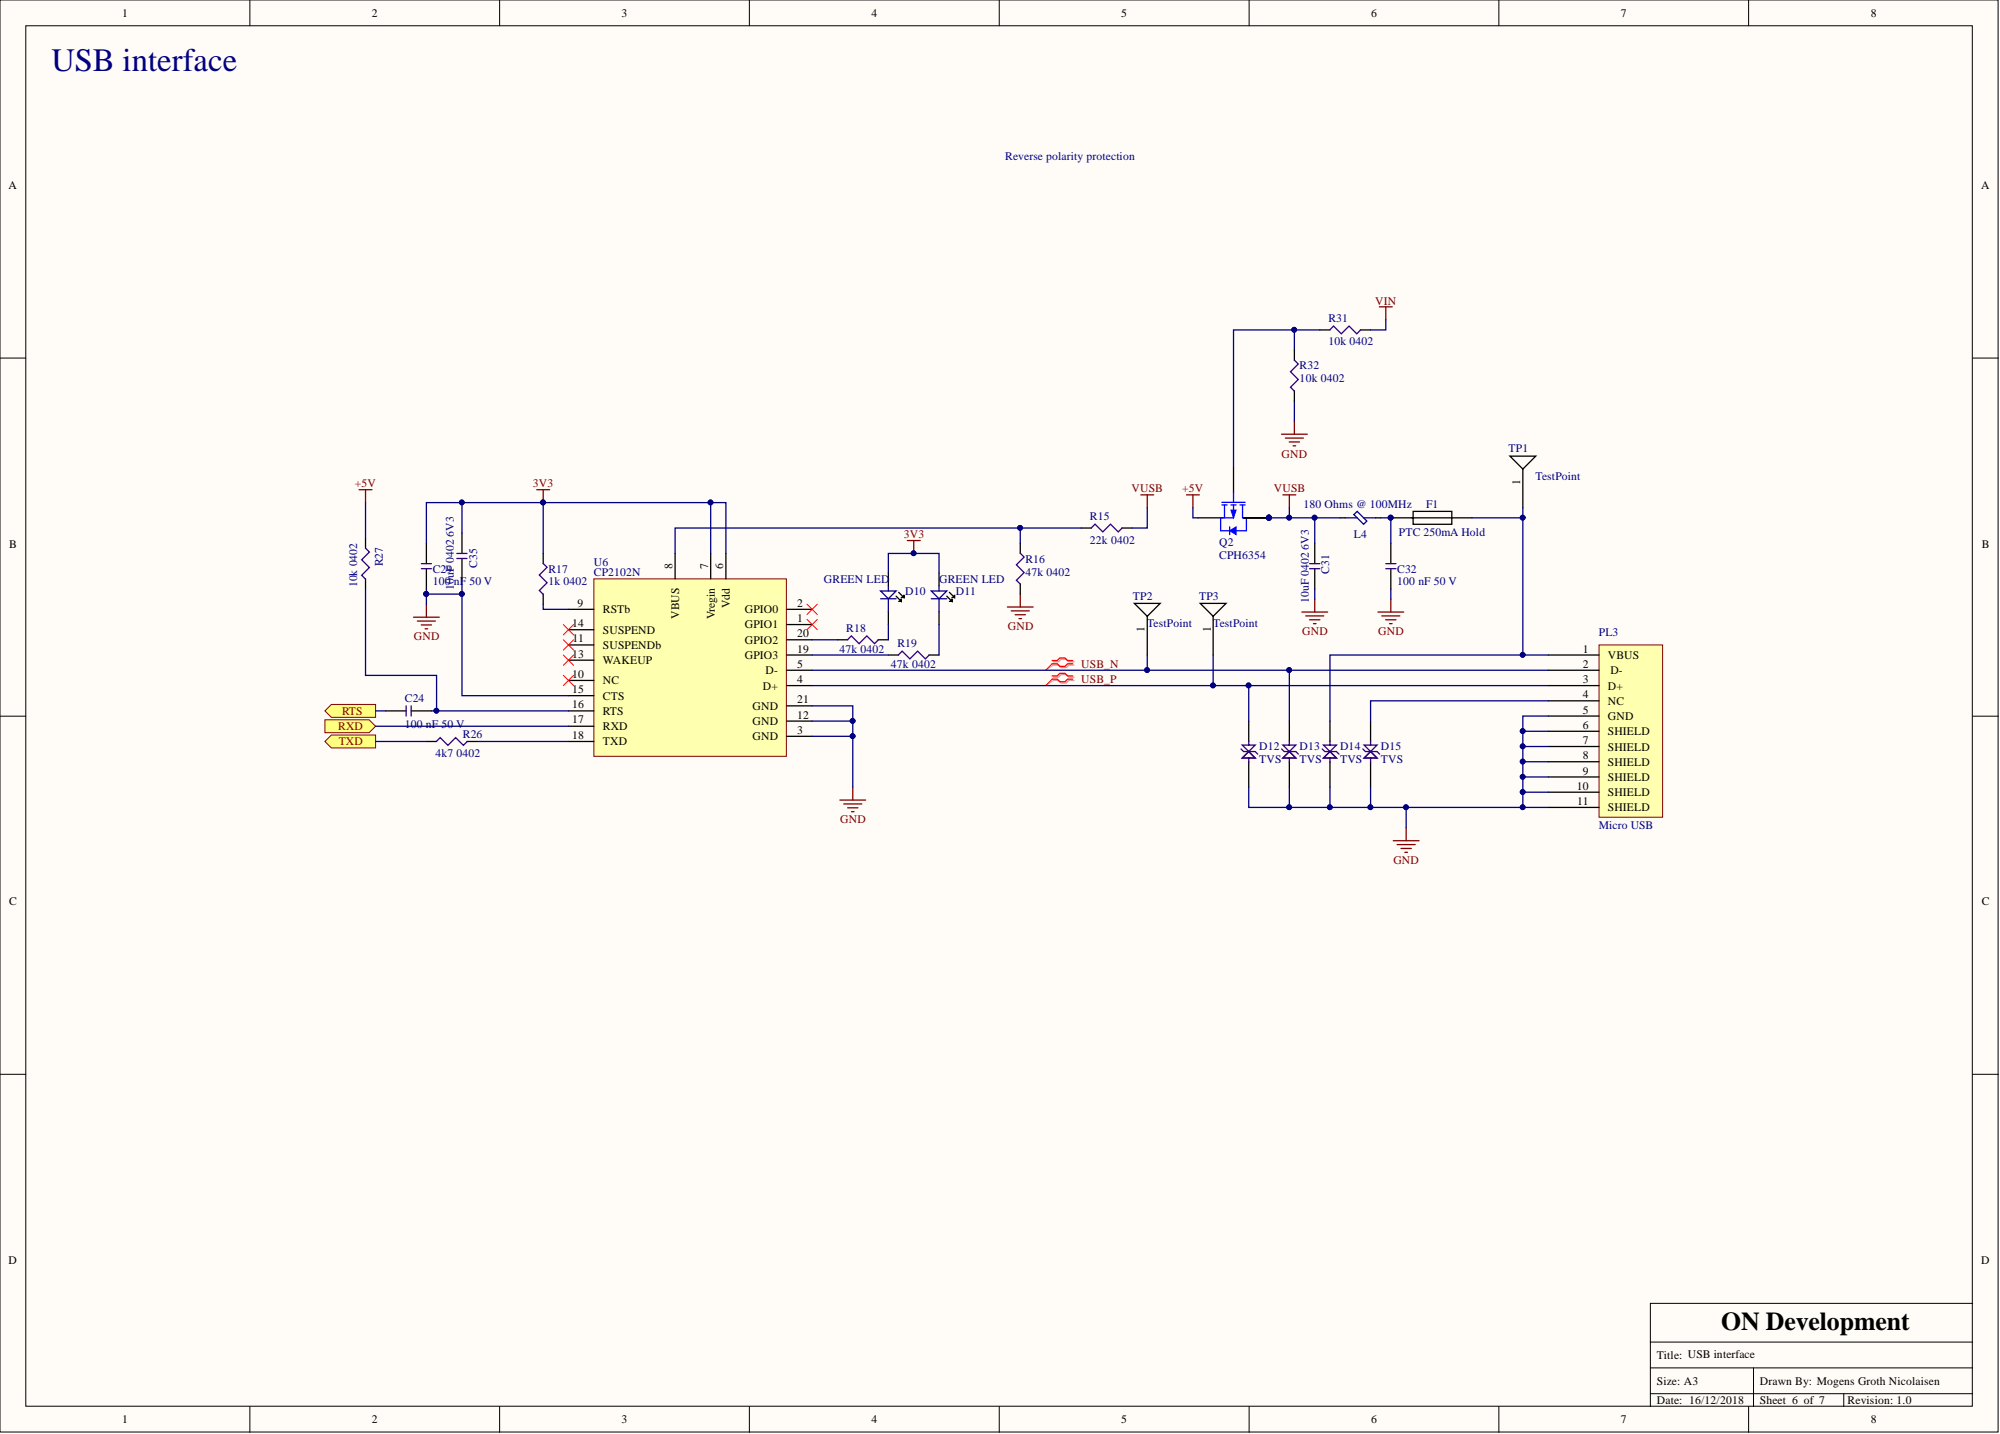
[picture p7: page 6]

4 | USB_ P | | 3
2 1 | | | 4

1 2
3 | | D 1 2 | D 1 4

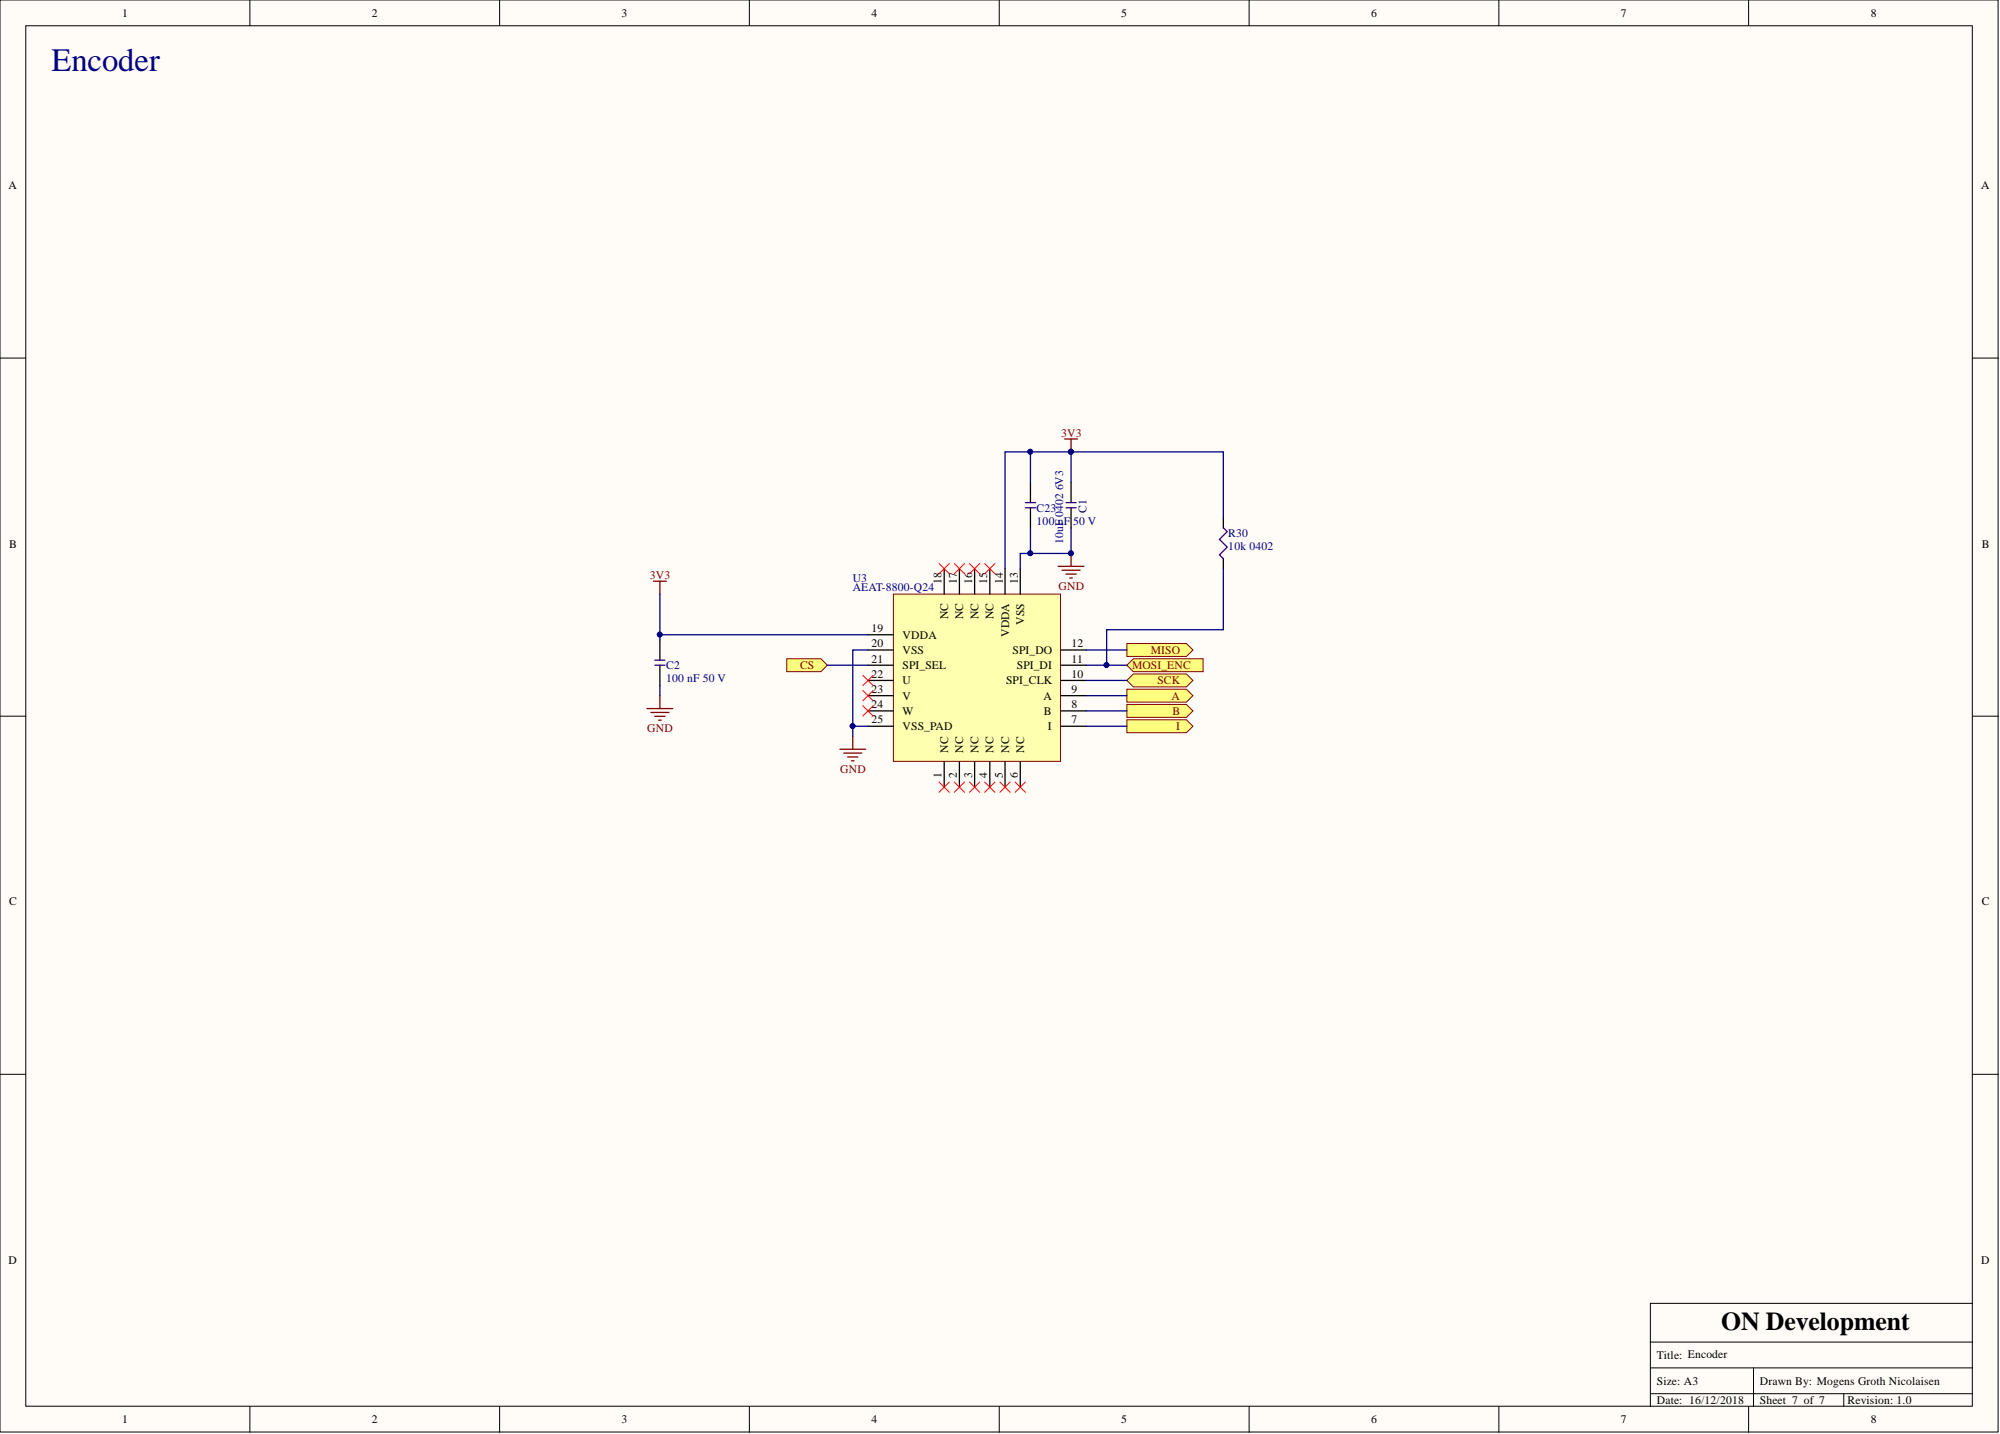
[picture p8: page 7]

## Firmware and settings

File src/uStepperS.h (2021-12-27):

/********************************************************************************************
* 	 	File: 		uStepperS.h 															*
*		Version:    2.3.0                                          						    *
*      	Date: 		December 27th, 2021  	                                    			*
*      	Authors: 	Thomas Hørring Olsen                                   					*
*					Emil Jacobsen															*
*                                                   										*	
*********************************************************************************************
*	(C) 2020																				*
*																							*
*	uStepper ApS																			*
*	www.ustepper.com 																		*
*	administration@ustepper.com 															*
*																							*
*	The code contained in this file is released under the following open source license:	*
*																							*
*			Creative Commons Attribution-NonCommercial-ShareAlike 4.0 International			*
* 																							*
* 	The code in this file is provided without warranty of any kind - use at own risk!		*
* 	neither uStepper ApS nor the author, can be held responsible for any damage				*
* 	caused by the use of the code contained in this file ! 									*
*                                                                                           *
********************************************************************************************/
/**
* @file uStepperS.h
*
* @brief      Function prototypes and definitions for the uStepper S library
*
*             This file contains class and function prototypes for the library,
*             as well as necessary constants and global variables.
*
* @author     Thomas Hørring Olsen (thomas@ustepper.com)
*
*	\mainpage Arduino library for the uStepper S Board
*	
*	This is the uStepper S Arduino library, providing software functions for the different features of the uStepper S board.
*
*	\par Features
*	The uStepper S library contains the following features:
*
*	- Dropin feature for applications like 3D printers
*	- Closed loop PID position controller
*	- Control of RC servo motors
*	- Measure the current position of the shaft (absolute, multiple revolutions)
*	- Measure the current speed of the motor 
*	- Stall detection for use in e.g. limit detection functionality 
*	
*	The library uses timer 1 in order to function properly, meaning that unless the user of this library
*	can accept the loss of some functionality, this timer is unavailable and the registers associated with these timers
*	should not be reconfigured.
*
*	Timer one is used for sampling the encoder in order to provide the ability to keep track of both the current speed and the
*	angle moved since the board was reset (or a new home position was configured). Also the drop-in features missed step detection and 
*	correction is done in this timer. 
*	
*	\par EEPROM Usage information
*	\warning
*	\warning Please be aware that the uStepper uses the EEPROM to store settings related to the Dropin application.
*	\warning If you are not using this, then this has no impact for your application, and you can ignore this section !
*	\warning
*	\warning EEPROM address 0 to 15 contains the different settings for dropin. If your application uses the EEPROM,
*	\warning Please use another location than these !
*
*	\par Installation
*	To install the uStepper S library into the Arduino IDE, perform the following steps:
*
*	- Go to Sketch->Include Libraries->Manage Libraries... in the arduino IDE
*	- Search for "uStepper S", in the top right corner of the "Library Manager" window
*	- Install uStepper S library 
*	
*	The library is tested with Arduino IDE 1.8.11
*	
*	\warning MAC users should be aware, that OSX does NOT include SILABS VCP drivers, needed to upload sketches to the uStepper S, by default. This driver should be 
*	downloaded and installed from SILABS's website:
*	\warning https://www.silabs.com/products/development-tools/software/usb-to-uart-bridge-vcp-drivers
*	\warning             The uStepper S should NOT be connected to the USB port while installing this driver !
*	\warning This is not (commonly) a problem for windows/linux users, as these drivers are most often already included in the OS
*
*	\par Copyright
*
*	(C)2020 uStepper ApS	
*																	
*	www.ustepper.com 																	
*
*	administration@ustepper.com 														
*																							
*	<img alt="Creative Commons License" style="border-width:0" src="https://i.creativecommons.org/l/by-nc-sa/4.0/88x31.png" />																
*
*	The code contained in this file is released under a <a rel="license" href="http://creativecommons.org/licenses/by-nc-sa/4.0/">Creative Commons Attribution-NonCommercial-ShareAlike 4.0 International License</a>	
*																							
*	The code in this library is provided without warranty of any kind - use at own risk!		
* 	neither uStepper ApS nor the author, can be held responsible for any damage		
* 	caused by the use of the code contained in this library ! 	
*
*	\par Known Bugs
*	- does not properly release motor in dropin mode
*
*	\author Thomas Hørring Olsen (thomas@ustepper.com)
*	\par Change Log
*	\version 2.1.0:
*	- Fixed checkOrientation to work with Closed loop and dropin modes
*	- Fixed stallguard feature
*	- Modified examples to library update  
*	\version 2.0.0:
*	- Changed name of "brake()" function in uStepper Class to "setBrakeMode()"
*	- Implemented "setBrakeMode()" function in uStepper Class to choose between freewheel, braking with low side fets shorted and brake with specified hold current. default = brake with low side fets shorted
*	- "setHome" argument of ustepper class "setup" function is now used
*	- Implemented "checkOrientation()" function in uStepper Class, to check the orientation of the motor cable, and invert direction if needed.
*	- Added 3 moves in "checkOrientation()" function in uStepper Class, to check orientation instead of just 1
*	- Removed check for motor cable orientation from "setup()" function in uStepper Class. Users actively needs to call the "checkOrientation" function from uStepper Class, if they need this feature, AFTER calling the "setup()" function
*	- Disabled driver on MCU reset while setting up, to avoid the motor spinning on startup if power was removed during motor movement
*	- Moved the absolute position counter into the encoder getangle function
*	- Added a LP filter on the absolute position data in the encoder function (so, getAngleMoved is filtered)
*	- Stall detection removed from timer1
*	- Variable filter depending on mode set in setup routine
*	- Removed obsolete things in setup routine and timer1
*	- Made new velocity measurement for encoder values
*	- Made the control threshold for closed loop control variable and intrduced a function for editing it
*	- Changed timer1 interrupt frequency to 2KhZ for all other modes than DROPIN
*	- Added option to choose how long the "checkOrientation()" function in UstepperS class should move during check
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

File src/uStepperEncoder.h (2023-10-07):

/********************************************************************************************
* 	 	File: 		uStepperEncoder.h														*
*		Version:    2.3.0                                          						    *
*      	Date: 		December 27th, 2021  	                                    			*
*      	Authors: 	Thomas Hørring Olsen                                   					*
*					Emil Jacobsen															*
*                                                   										*	
*********************************************************************************************
*	(C) 2020																				*
*																							*
*	uStepper ApS																			*
*	www.ustepper.com 																		*
*	administration@ustepper.com 															*
*																							*
*	The code contained in this file is released under the following open source license:	*
*																							*
*			Creative Commons Attribution-NonCommercial-ShareAlike 4.0 International			*
* 																							*
* 	The code in this file is provided without warranty of any kind - use at own risk!		*
* 	neither uStepper ApS nor the author, can be held responsible for any damage				*
* 	caused by the use of the code contained in this file ! 									*
*                                                                                           *
********************************************************************************************/
/**
* @file uStepperEncoder.h
*
* @brief      Function prototypes and definitions for the AEAT8800-Q24 Encoder
*
*             This file contains class and function prototypes for the AEAT8800-Q24 Encoder,
*             as well as necessary constants and global variables.
*
* @author     Thomas Hørring Olsen (thomas@ustepper.com)
*/
#include <Arduino.h>

#define CS PB2 /**< Chip select for AEAT-8800-Q24 - Pin 10 on ATmega328pB */
#define DIN PB3 /**< Data in for AEAT-8800-Q24 - Pin 11 on ATmega328pB (MOSI) */
#define DO PB4 /**< Data out for AEAT-8800-Q24 - Pin 12 on ATmega328pB (MISO) */
#define CLK PB5 /**< Clock signal for AEAT-8800-Q24 - Pin 13 on ATmega328pB (SCK) */

#define ENCODERDATATOSTEP 51200.0/65536.0 /**< Constant to convert raw encoder data to 1/256th steps*/
#define ENCODERDATATOREVOLUTIONS 60.0/65536.0 /**< Constant to convert raw encoder data to revolutions */
#define ANGLETOENCODERDATA 65535.0/360.0 /**< Constant to convert angle to raw encoder data */

/**
 * @brief      Prototype of class for the AEAT8800-Q24 encoder
 *
 *             This class enables the user of the library to access the AEAT8800-Q24
 *             encoder on the uStepper S board.
 */
class uStepperEncoder
{
	public:
		/**
		 * @brief	Constructor of uStepperEncoder class
		 */
		uStepperEncoder(void);

		/**
		 * @brief		Initiation of the encoder
		 *
		 *				This function initiates all the registers of the encoder.
		 *
		 * @param[in]	_pointer - reference to the uStepper S object
		 */
		void init( uStepperS * _pointer );

		/**
		 * @brief      Define new reference(home) position
		 *
		 *             This function redefines the reference position to the current
		 *             angle of the shaft
		 * 
		 * 	@param[in]  initialAngle - Home position offset from zero
		 */
		void setHome( float initialAngle = 0 );

		/**
		 * @brief      Return the current shaft angle in degrees
		 *
		 *             This function returns the last captured shaft angle.
		 *             The resolution of the angle returned by this function is
		 *             0.0054931640625 degrees (16 bits)
		 *
		 * @return     Floating point representation of the current motor shaft
		 *             angle
		 */
		float getAngle( void );

		/**
		 * @brief      	Return the current shaft angle in raw encoder readings
		 *
		 *             	This function returns the last captured shaft angle, as 
		 *				output directly from the encoder.
		 *             	The resolution of the angle returned by this function is
		 *             	16 bits
		 *
		 * @return     	raw 16 bit encoder representation of the current motor shaft
		 *             	angle
		 */
		uint16_t getAngleRaw( void );

		/**
		 * @brief      Returns the angle moved from reference position in degrees
		 *
		 *             This function returns the angle moved from the shaft
		 *             reference position. When the uStepper S is first powered on,
		 *             the reference position is reset to the current shaft
		 *             position, meaning that this function will return the angle
		 *             rotated with respect to the angle the motor initially had. It
		 *             should be noted that this function is absolute to an
		 *             arbitrary number of revolutions !
		 *
		 *             The reference position can be reset at any point in time, by
		 *             use of the setHome() function.
		 * 
		 * @param[in]  filtered - if true, the function returns the filtered angle. if false, the unfiltered angle is returned
		 *
		 * @return     The angle moved in degrees.
		 */
		float getAngleMoved( bool filtered = true);

		/**
		 * @brief      Returns the angle moved from reference position in raw encoder readings
		 *
		 *             This function returns the angle moved from the shaft
		 *             reference position. When the uStepper S is first powered on,
		 *             the reference position is reset to the current shaft
		 *             position, meaning that this function will return the angle
		 *             rotated with respect to the angle the motor initially had. It
		 *             should be noted that this function is absolute to an
		 *             arbitrary number of revolutions !
		 *
		 *             The reference position can be reset at any point in time, by
		 *             use of the setHome() function.
		 * 
		 * @param[in]  filtered - if true, the function returns the filtered angle. if false, the unfiltered angle is returned
		 *
		 * @return     The angle moved in raw encoder readings.
		 */
		int32_t getAngleMovedRaw( bool filtered = true );

		/**
		 * @brief      Measure the current speed of the motor
		 *
		 *             This function returns the current speed of the motor. The
		 *             speed is not calculated in this function, it is merely
		 *             returning a variable. The speed is calculated in the
		 *             interrupt routine associated with timer1.
		 *
		 * @return     Current speed in 1/256th steps per second
		 */
		float getSpeed(void);

		/**
		 * @brief      Measure the current speed of the motor
		 *
		 *             This function returns the current speed of the motor. The
		 *             speed is not calculated in this function, it is merely
		 *             returning a variable. The speed is calculated in the
		 *             interrupt routine associated with timer1.
		 *
		 * @return     Current speed in RPM
		 */
		float getRPM(void);
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

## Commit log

2018-07-19 Added TIMER1_COMPA
    Timer1 now continuously captures the angle.
2018-08-24 Testing stealthChop and fixes
    [uStepperS.cpp, uStepperS.h]
2018-10-04 fixed encoder comm. Driver CS was pulled low (initial state after defining pin as output). this caused both encoder and driver to talk at the same time causing signal reflections. changed setup in uS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
    [uStepperDriver.cpp, uStepperDriver.h, uStepperEncoder.cpp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]
2018-10-20 Update
    Stealth doesnt work right now, dont know why. Fix in next commit
    [uStepperDriver.cpp, uStepperDriver.h, uStepperS.cpp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]
2018-10-26 Fixing moveSteps and adding example
    [uStepperDriver.cpp, uStepperS.cpp]
2018-10-28 Moving functionality from Driver to main class
2018-10-31 Encoder and driver additions
2018-11-05 Speed calculation from encoder
2018-11-15 Free wheeling
2019-05-07 fixed problem with acceleration/deceleration settings
    [uStepperDriver.cpp, uStepperS.cpp, uStepperS.h]
2019-05-13 small bugfixes and added documentation
    [uStepperDriver.cpp, uStepperDriver.h, uStepperEncoder.cpp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]
2019-05-21 prepared for 1.0.1 release. added documentation, fixed accel/decel bug
    [DropIn.ino, uStepperDriver.cpp, uStepperS.cpp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]
2019-05-28 increased angle moved during motor connector orientation check to 10 degrees
2019-06-03 edited stall detection
    sensitivity actually does something now
    [uStepperS.cpp, uStepperS.h]
2019-06-10 Added HW source files for uStepper S
    [Coverpage.SchDoc, MCU+IO.SchDoc, Main.SchDoc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]
2019-10-10 correction of encoder feedback
    [uStepperEncoder.cpp]
2019-10-26 Filtering on encoder data
    Added a LP filter on the raw data - might impact the PID and drop-in loops stability because of the introdued lag
    [uStepperEncoder.cpp]
2019-11-04 added prototype for cmpfunc in ustepperencoder.h
2020-01-07 Stall detect edited
    New method for stall detection - still needs testing and adapting of the rest of the code (e.g. stallsensitivity)
    [uStepperS.cpp]
2020-01-21 filtering
    Filter added, timer1 runs at 3x speed, new encoder based speed feedback and new stall detection
    [uStepperEncoder.cpp, uStepperEncoder.h, uStepperS.cpp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]
2020-01-23 Corrected setHome feature in setup
    The setHome feature that zeros the encoder position at startup is now fixed so that it can be disabled in the setup
    [uStepperS.cpp]
2020-02-13 Testing TMC stallguard
    Using Stallguard2 features of TMC5130. Not yet working, trying some things out
    [Continous.ino, uStepperDriver.cpp, uStepperDriver.h]
2020-02-27 Stallguard using TMC5130
2020-03-14 reverted to working version
    [uStepperEncoder.cpp, uStepperEncoder.h, uStepperS.cpp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]
2020-03-14 bugfixes and new features. see "changes.txt" for details
    [uStepperDriver.cpp, uStepperDriver.h, uStepperS.cpp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]
2020-03-14 edited the filtering
2020-03-15 disabled driver on MCU reset while setting up
    [uStepperDriver.cpp, uStepperS.cpp]
2020-03-15 edited encoder stuff
2020-03-16 Fixed isStalled() and added examples
    Cleanup and fixes
    [StallguardIsStalled.ino, uStepperDriver.cpp, uStepperDriver.h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]
2020-03-26 small bugfixes. ready for test
    [LimitDetection.ino, StallguardIsStalled.ino, uStepperEncoder.cpp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]
2020-03-28 bugfixes added filter for speed estimation
    [Continous.ino, LimitDetection.ino, StallguardIsStalled.ino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]
2020-03-28 reset speed estimation filter on setHome
    [uStepperEncoder.cpp]
2020-06-03 Changed stall_speed in enableStallguard
    [uStepperDriver.cpp]
2020-06-04 stallguard dynamic speed
    added a parameter to make the stallguard threshold scale with speed - corrected the stallguard example to take this into account also.
    [StallguardIsStalled.ino, uStepperDriver.cpp, uStepperDriver.h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]
2020-06-07 moveToend
    move before stallguard enable
    [uStepperS.cpp]
2020-07-09 Corrected examples
    Tested all examples and added minor corrections/adjustments
    [Bounce.ino, ClosedLoopPosition.ino, Continous.ino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]
2020-07-11 corrected shaftdirection
    works with changing gconf
    [uStepperDriver.cpp, uStepperS.cpp, uStepperS.h]
2020-07-11 edited description
    corrected description of movetoangle
    [uStepperS.h]
2020-08-03 Fixed driver velocity
    Driver velocity was not handled correctly
    [uStepperDriver.cpp, uStepperS.cpp, uStepperS.h]
2020-09-22 Gyro example code added
2020-10-02 Added example showing status of magnet.
2020-12-19 Added encoder stall feature
    And example
    [EncoderStall.ino, uStepperEncoder.cpp, uStepperEncoder.h]
2020-12-20 update to make negative direction work with encoder stall
    [uStepperEncoder.cpp]
2020-12-21 stalldetect update
2020-12-21 refining encoderstall
2021-01-18 update stallguard example to print stall value
    [StallguardIsStalled.ino]
2021-01-19 Examples added
    for stall sensitivity calibration
    [EncoderStallSensitivityCalibration.ino, StallguardIsStalled.ino, StallguardSensitivityCalibration.ino]
2021-11-28 changed uStepper Servo library to use timer PWM instead. now only available on pin3, more will come
2023-08-13 Update StallguardSensitivityCalibration.ino
    minor correction for the feature
    [StallguardSensitivityCalibration.ino]
